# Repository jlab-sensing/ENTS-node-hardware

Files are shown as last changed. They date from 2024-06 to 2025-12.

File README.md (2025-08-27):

# Environmental NeTwork Sensor (ENTS) Node Hardware

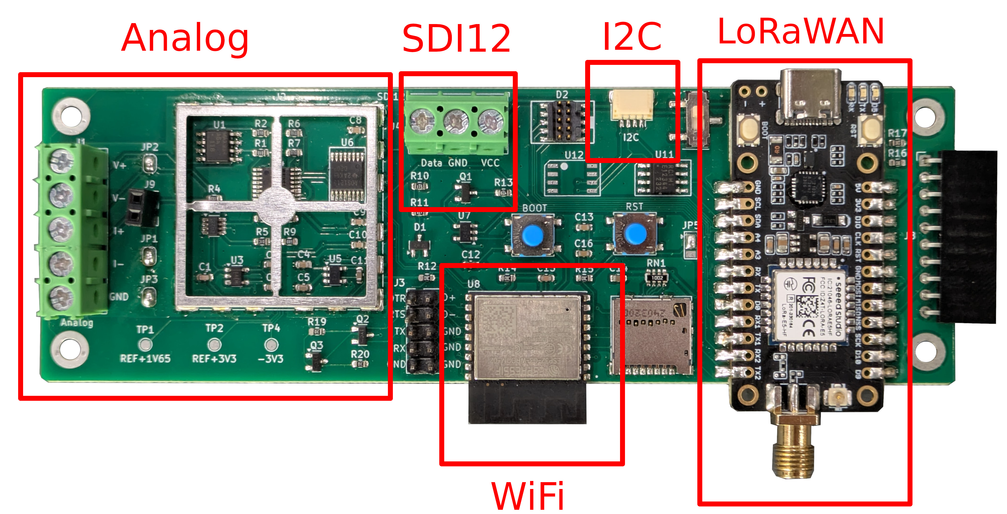
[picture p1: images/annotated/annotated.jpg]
Annotated Soil Power Sensor


This repo contains the EagleCAD source files for the PCB design of the Soil Power Sensor. The Soil Power Sensor is a iteration on the design of CurrentSense by Lab11(https://github.com/lab11/CurrentSense).

## BOM

The bill of materials is available digitally at https://octopart.com/bom-tool/nBygYAnz or as csv in `hardware/Soil Power Sensor.csv`.

There are two buttons not listed in the BOM for the esp32 `BOOT` and `EN`. These are cheaply available from amazon. Look for one with a 6mm by 6mm form factor.

Generate the BOM from the schematic editor (`Tools -> Generate Bill of Materials...`) and use the view *Order*.

## Assembly and QA Instructions

### Solder SMD components

We suggest ordering the boards SMD assembled through a PCB assembly service and have used [JLCPCB](https://jlcpcb.com/) in the past. Every component except the Wio-E5 module, 5-pin screw terminals, 3-pin screw terminals, and pin headers can be soldered by the assembly service. The component `U13` should not be populated by default and is used to expand the non-volatile memory of sensor measurements.

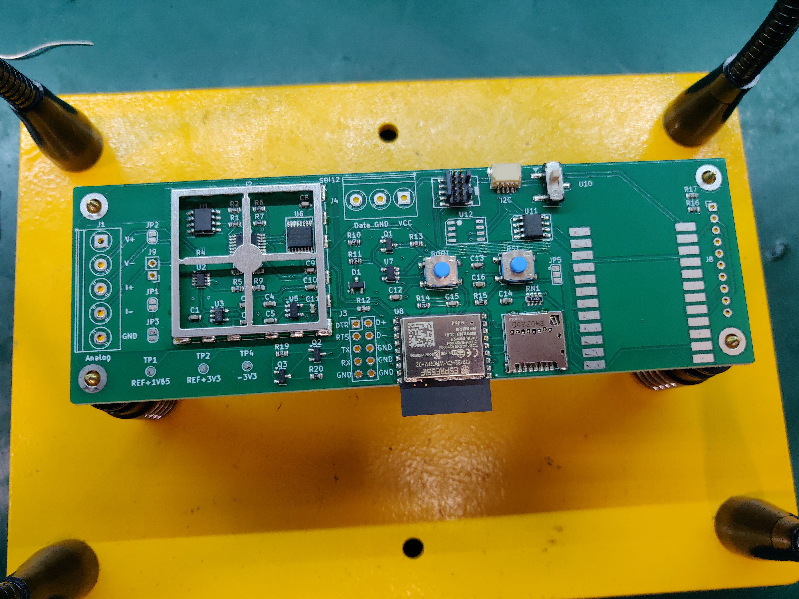
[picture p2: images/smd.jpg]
SMD Populated Board


### Solder Remaining Components

*Before soldering* visually inspect the boards for any solder bridges and defects. You do not want to solder the Wio-E5 module to a defective board as it accounts for half the cost of the board and cannot be desoldered easily.

1. Solder screw terminals at `J1`, `J4`, male pin-headers at `J3`, female right-angle pin headers at `J8`, and female pin headers at `J9`.
2. Solder the Wio-E5 module to the board. The USB-C connector should be facing the edge of the board closest to the switch, and RF terminal facing the microSD card module. The RF terminal should touching the edge of the board.
3. Use a multimeter to test for shorts between `GND` and `TP1`, `TP2`, `TP4`, `5V` on the Wio-E5, `3V3` on the Wio-E5, and `Vcc` on the 3-pin screw terminal. `TP4` maay display a resistance value due to capacitors.

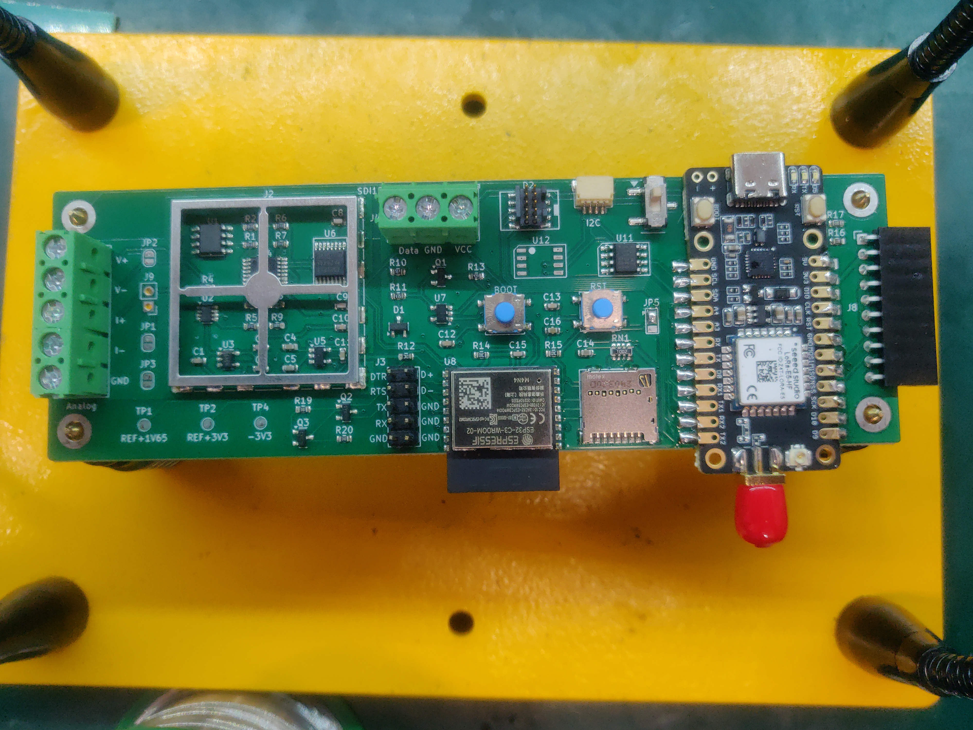
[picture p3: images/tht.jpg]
THT Populated Board


> NOTE: `J9` should be soldered with a female header to be used to connect a load. We did not have any 2x1 headers on hand so it is not shown in the picture.

### Check Power Rails

Then, power the device through the USB-C terminal with the power switch in the "UP" (close to nearest board edge). Verify the voltages at the test points match what is shown in the table. Some rails may be put in power down state by default and require firmware to be running to enable them.

`TP6` is used to used to connect the battery to the Wio-E5 module.

| Test point  | Signal | Voltage |
| ---  | --- | --- |
| `TP1` | `REF+1V65` | +1.65V  |
| `TP2` | `REF+3V3`  | +3.3V |
| `3V3` (Wio) | `+3V3` | +3.3V |
| `TP4` | `-3V3` | -3.3V |
| `TP5` | `VCC` | 5V |
| `5V` (Wio)  | `VUSB` | 5V |

### Load Firmware

See [ENTS-node-firmware](https://github.com/jlab-sensing/ENTS-node-firmware) for instructions on loading firmware on the device.

## Header definitions

### D2 (STM32 SWD)

Serial wire debug (SWD) port for stm32. To load the bootloader, hold `BOOT`, press and release `RST`, then release `BOOT`. Then you should be able to connect to the device.

### J9 (ESP32 Debug Header)

### J3 (ESP32 UART)

UART TX and RX pins to connect to the esp32 bootloader. Intended to be use with a USB to UART converter and `esptool.py`.

### J9 (Battery Connector)

Connect a battery module to the ENTS board. The header is reversible has the following pinout, where `~` represent inverse logic:

| `GND` |
| `3V3` |
| `~PG` |
| `~CHG` |
| `VBAT` |
| `VBAT` |
| `~CHG` |
| `~PG` |
| `3V3` |
| `GND` |

## Measurement configurations

The soil power sensor has multiple measurement configurations. The most common use case is *Common GND* which gives single ended measurements with low-side sensing.

### Independent Inputs (Default)

| Jumper | Bridged |
|---|---|
| `JP1` | No |
| `JP2` | No |
| `JP3` | No |

| Resistor | Value |
|---|---|
| `Rsense1` | DNP |

Inputs `Voltage`, `Current`, `GND` are all independent from each other, therefore the most modular configuration. Use this mode when you want to measure a voltage/current difference that is not relative to `GND`. The `GND` connection must be connected to the common ground of the measured device.

### Common `GND`

| Jumper | Bridged |
|---|---|
| `JP1` | Yes |
| `JP2` | No |
| `JP3` | Yes |

| Resistor | Value |
|---|---|
| `Rsense1` | 0 ohms |

The negative terminals of `Voltage` and `Current` are tied to ground. Both measurements will be relative to ground. Connect common ground to the negative terminals or `GND` terminal.

### Internal load

| Jumper | Bridged |
|---|---|
| `JP1` | Yes |
| `JP2` | Yes |
| `JP3` | Yes |

| Resistor | Value |
|---|---|
| `Rsense1` | Any |

The configuration uses a on-board resistor for `RSENSE1`. The resistor is chosen based on the desired range of input measurements. The board uses a high-side current measurements.

## Userful links

Links for generating production files and BOM for [JLCPCB](https://jlcpcb.com/)

- [Gerber and drill/map files](https://jlcpcb.com/help/article/how-to-generate-gerber-and-drill-files-in-kicad-8)
- [BOM and centroid files](https://jlcpcb.com/help/article/How-to-generate-the-BOM-and-Centroid-file-from-KiCAD)

## License & Copyright

The Soil Power Sensor board design files are licensed under the Solderpad Hardware License (wraparound license of Apache License).

## Maintainers

- John Madden - [jmadden173](https://github.com/jmadden173)

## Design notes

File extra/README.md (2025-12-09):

# Extras

Extra resources supporting development.

- `analog_multiplexer/`: PCB for multiplexing analog input channels
- `battery_connector/`: PCB for converting 2.54mm header to 5-pin JST connector
- `i2c_breakout/`: PCB to expose additional I2C connectors and regulate to a 3.3V source
- `mounting_plate/`: 3D-printed mounting plate for ENTS-nodes
- `newbatt`: PCB for powering the ENTS-node from a battery
- `sdi12_breakout`: PCB to expose additional SDI-12 terminals
- `usb_to_ttl/`: PCB for plug-in-play debugging of the esp32

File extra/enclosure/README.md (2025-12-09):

# Enclosure V2

> NOTE: This is an iteration on the enclosure designed by UC San Diego students available [here](https://github.com/jlab-sensing/ENTS-enclosure). Notably the board mounts to the screw portion of the enclosure rather than the static cap. This makes assembly/removal of the board easier. The original repo is a good reference for detailed assembly instructions and cost.

## Instructions

1. 3D print the *base*, *mount*, and *guide*.
1. Cut PVC tube to desired length (TBD length).
1. Use PVC primer and cement to attach both end caps.
1. Use the *guide* to drill holes in the screw off end cap.
1. Use a step drill to enlarge the holes to fit cable glands.
1. Press threaded inserts into the mount.
1. Superglue the mount to the base.
1. Superglue the base to the screw cap.
1. Install cable glands.

## Materials

| Item | Link |
|---|---|
| PVC Tube | [McMaster](https://www.mcmaster.com/2426k93/) |
| PVC End Cap | [McMaster](https://www.mcmaster.com/9102K224/) |
| PVC Threaded Adapter | [McMaster](https://www.mcmaster.com/9102K354/) |
| PVC Threaded End Cap | [McMaster](https://www.mcmaster.com/9102K334/) |
| PVC Primer | [McMaster](https://www.mcmaster.com/18815K51/) |
| PVC Cement | [McMaster](https://www.mcmaster.com/74605a911/) |
| 3D Printer | Prusa Preferred |
| M3 x 6mm x 5mm Inserts | [Amazon](https://www.amazon.com/dp/B0CTCSJ8YT?ref=fed_asin_title&th=1) |
| M3 Standoffs | [Amazon](https://www.amazon.com/dp/B07KWVD986?ref=fed_asin_title) |
| M3 x 6mm Screws | [Amazon](https://a.co/d/5NEkSzM) |
| Cable Gland (Teros) | TODO |
| Cable Gland (Power) | TODO |

## Pictures

TODO

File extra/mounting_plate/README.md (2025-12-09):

# Mounting Plate for ENTS-nodes

3D-printed mounting plate for ENTS-nodes. Useful for airgapping metal pins from conductive surfaces and mounting the nodes securely.

## Materials

| Item | Link |
|---|---|
| M3 x 6mm x 5mm Inserts | [Amazon](https://www.amazon.com/dp/B0CTCSJ8YT?ref=fed_asin_title&th=1) |
| M3 Standoffs | [Amazon](https://www.amazon.com/dp/B07KWVD986?ref=fed_asin_title) |
| M3 x 6mm Screws | [Amazon](https://a.co/d/5NEkSzM) |

## Photo

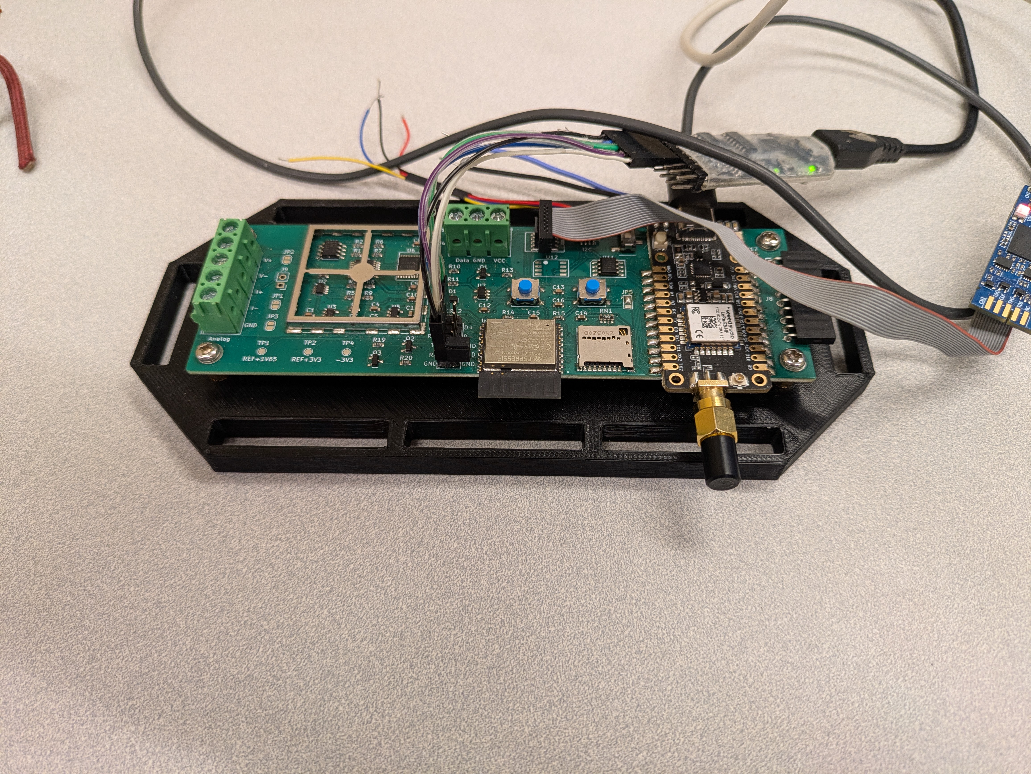
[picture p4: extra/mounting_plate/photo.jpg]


## Drawing

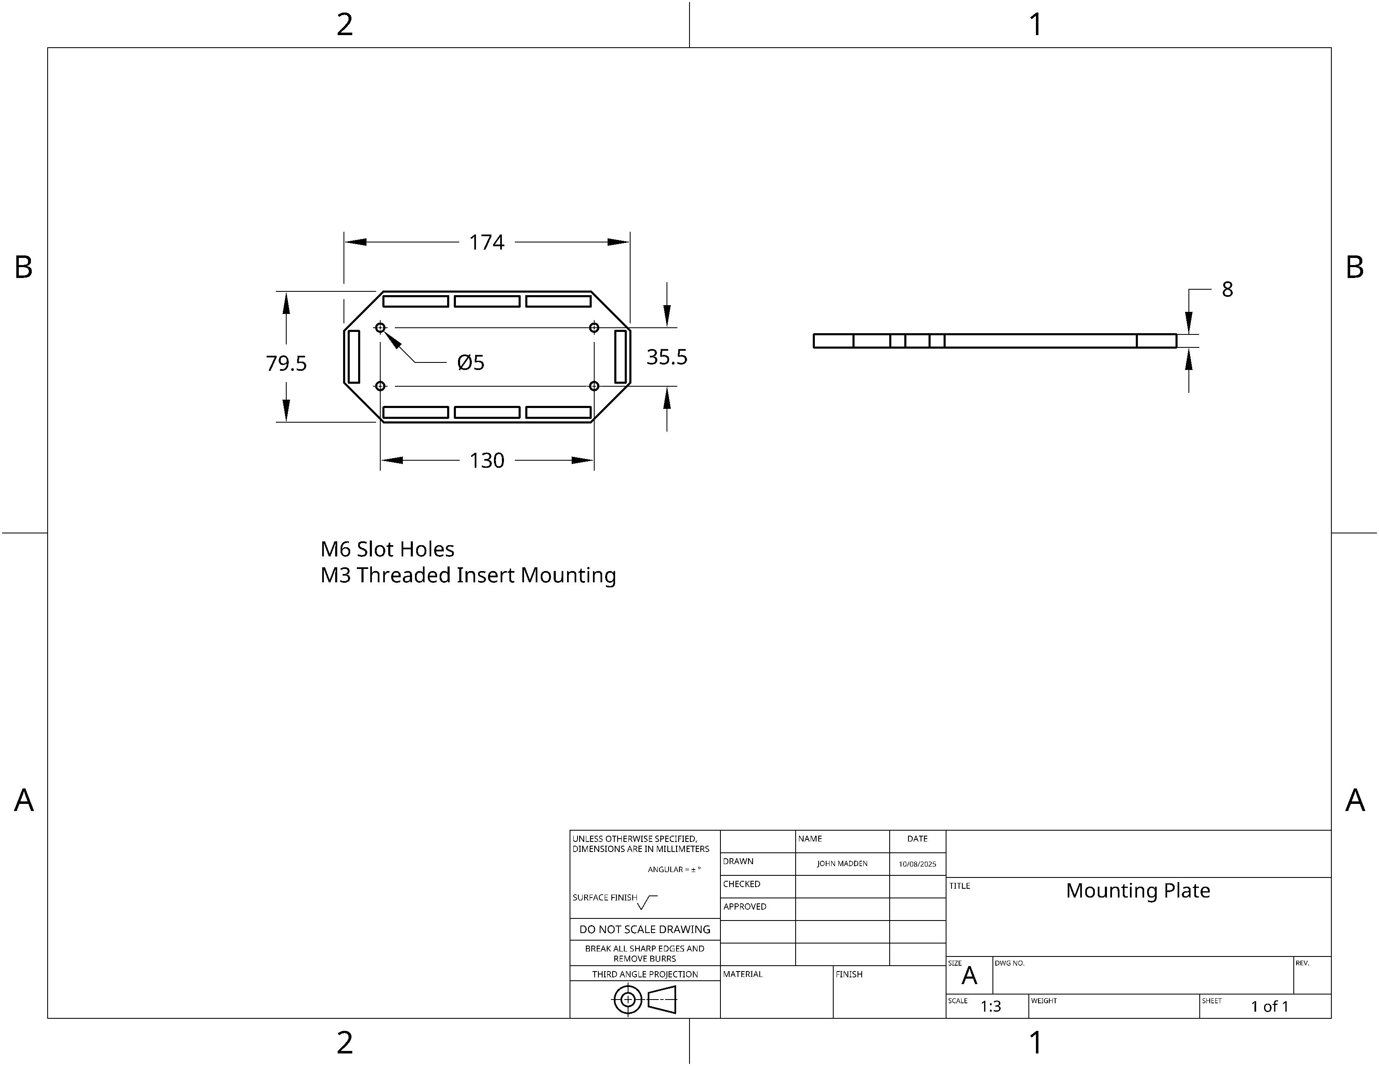
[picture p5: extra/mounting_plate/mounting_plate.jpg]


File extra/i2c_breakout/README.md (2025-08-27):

# SDI12 Breakout Board

This board add additional SDI-12 headers for connecting sensors. It also adds 3.5mm audio jacks that are commonly seen on SDI-12 sensors from METER.

| Top View | Bottom View |
| --- | --- |
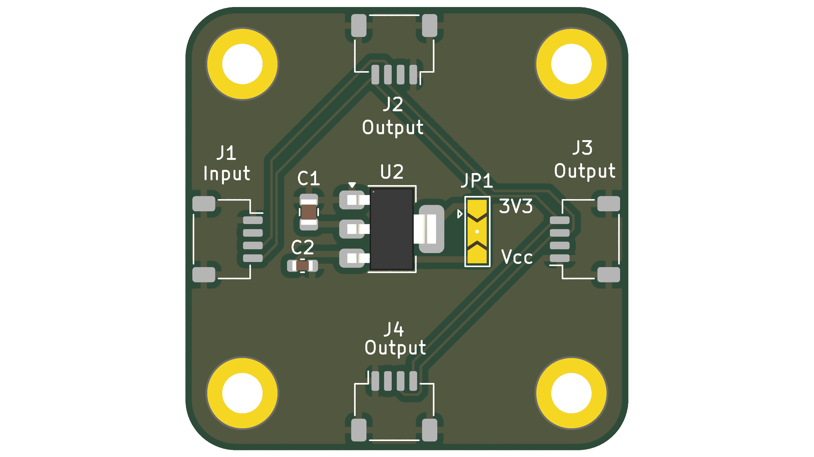
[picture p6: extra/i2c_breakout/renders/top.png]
Top View
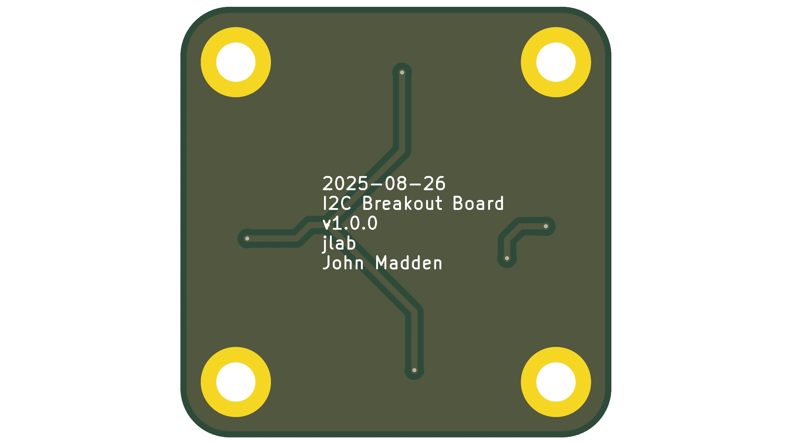
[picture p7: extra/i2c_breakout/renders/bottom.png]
Bottom View
|  |  |

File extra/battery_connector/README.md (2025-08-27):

# Battery Connector

The board adapts the old 10-pin molex connector to a better 5-pin JST connector.

| Top View | Bottom View |
| --- | --- |
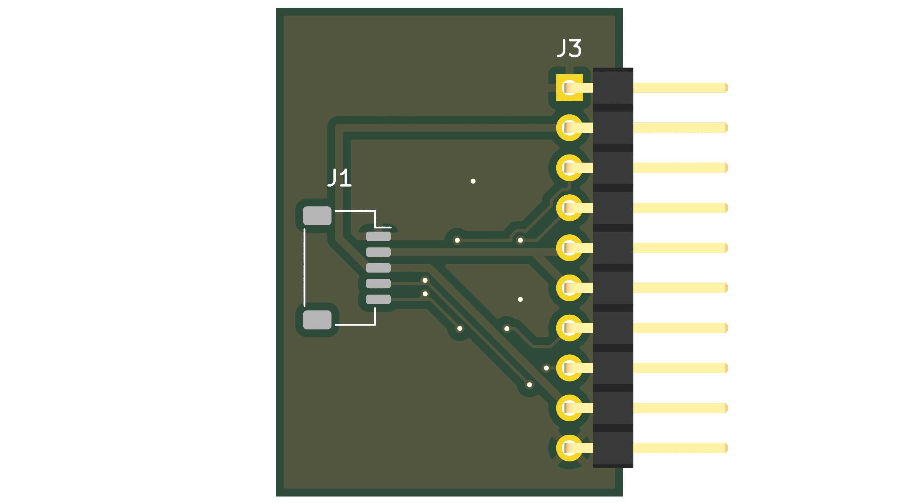
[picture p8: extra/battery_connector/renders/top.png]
Top View
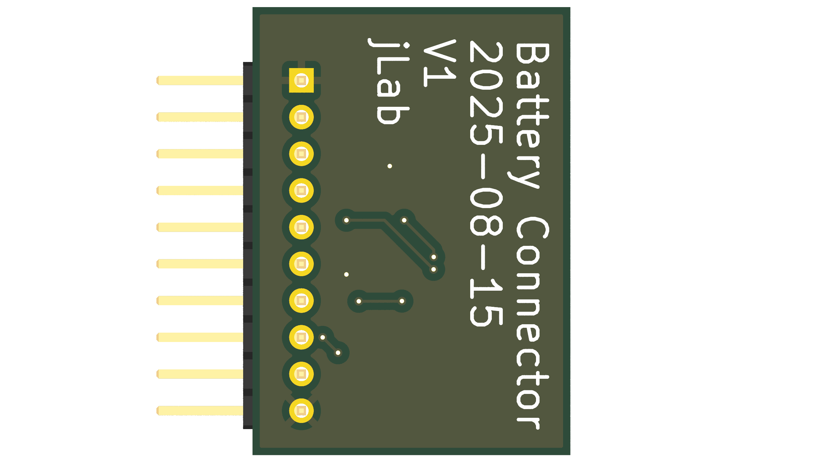
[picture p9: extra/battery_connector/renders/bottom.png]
Bottom View
|  |  |

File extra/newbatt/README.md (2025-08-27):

# Battery Board

The battery board adds two 18650 Li-ion battery and integrates a solar MPPT chip for charging. It uses a 5-pin JST connector to the ENTS board.

**Pin Configuration**

| # | Pin | Description |
|---| ---|---|
| 1 | GND | Ground |
| 2 | VBAT  | Battery voltage |
| 3 | 3.3V  | Regulated 3.3V |
| 4 | !PG | Power Good |
| 5 | !CHG  | Charging status |

| Top View |
| --- |
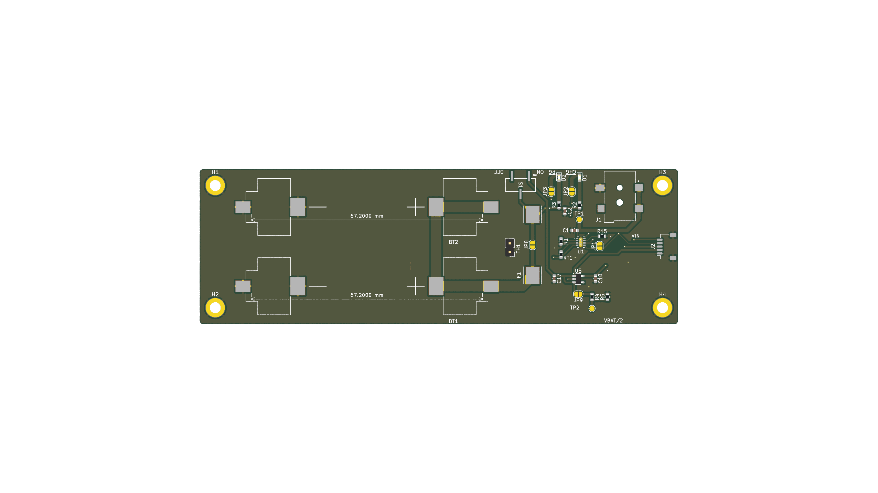
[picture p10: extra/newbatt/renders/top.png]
Top View
|  |

| Bottom View |
| --- |
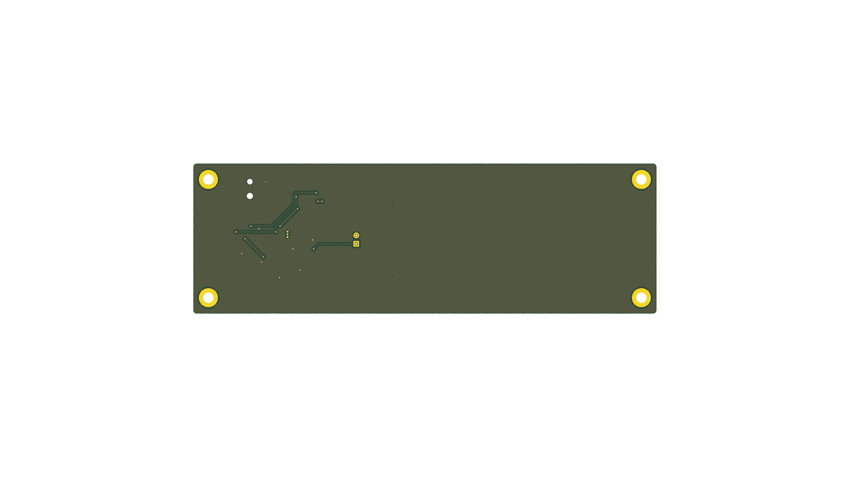
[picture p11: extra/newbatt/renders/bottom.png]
Bottom View
|  |

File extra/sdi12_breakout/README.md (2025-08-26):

# I2C Breakout Board

The breakout board is intended to add additional headers for external I2C devices. The header labeled input expects 5V input from the I2C header and steps the voltage down to `3V3` for compatibility with Adafruit devices. If this is not desired, the power jumper can be changed.

| Top View | Bottom View |
| --- | --- |
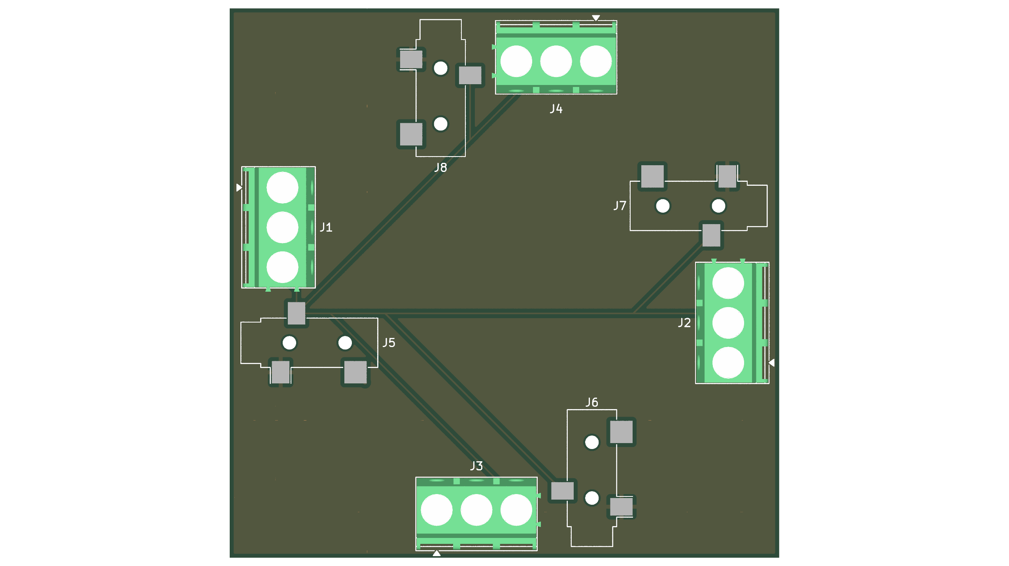
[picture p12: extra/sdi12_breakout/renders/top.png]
Top View
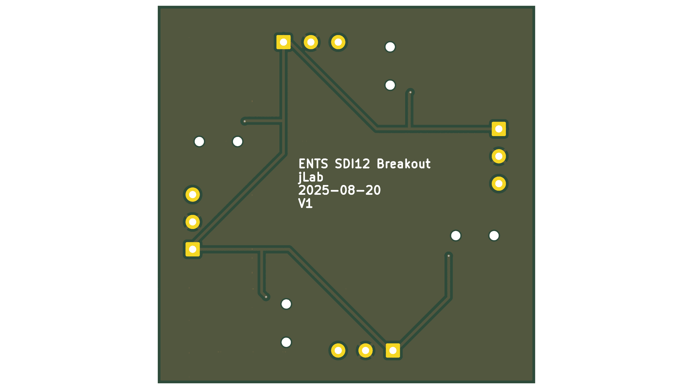
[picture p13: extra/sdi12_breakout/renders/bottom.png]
Bottom View
|  |  |

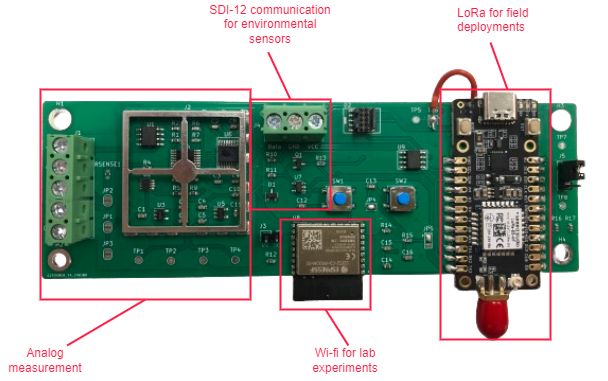
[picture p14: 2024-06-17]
images/sps.png

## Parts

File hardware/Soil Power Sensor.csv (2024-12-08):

Reference | Value | Footprint | Qty | MPN | LCSC
C1,C6,C7,C8,C9,C10,C12,C13,C15 | 0.1uF | Capacitor_SMD:C_0603_1608Metric | 9 | CC0603KPX7R7BB104
C4,C5,C11,C16 | 1uF | Capacitor_SMD:C_0603_1608Metric | 4 | CC0603KRX5R7BB105
C14 | 10uF | Capacitor_SMD:C_0603_1608Metric | 1 | CC0603KRX5R5BB106
D1 | BZX84Cxx | Package_TO_SOT_SMD:SOT-23 | 1 | BZX84C7V5LT1G | C12729
D2 | ARM10_DEBUG | Soil Power Sensor:ARM10_DEBUG | 1 | FTSH-105-01-LM-DV-K | C2874168
J1 | Screw_Terminal_01x05 | TerminalBlock_Phoenix:TerminalBlock_Phoenix_PT-1,5-5-5.0-H_1x05_P5.00mm_Horizontal | 1 | 1935190
J2 | RFShield_OnePiece | RF_Shielding:Wuerth_36103305_30x30mm | 1 | 36103305S | C7386557
J3 | Debug | Connector_PinHeader_2.54mm:PinHeader_2x05_P2.54mm_Vertical | 1
J4 | Conn_01x03 | TerminalBlock_Phoenix:TerminalBlock_Phoenix_PT-1,5-3-5.0-H_1x03_P5.00mm_Horizontal | 1 | 1935174
J5 | Micro_SD_Card | Connector_Card:microSD_HC_Molex_104031-0811 | 1 | 1040310811 | C585350
J6 | RFShield_OnePiece |  | 1 | 36003300S
J7 | Conn_01x04_Socket | Connector_JST:JST_SH_SM04B-SRSS-TB_1x04-1MP_P1.00mm_Horizontal | 1 | SM04B-SRSS-TB | C160404
J8 | Conn_01x10 | Connector_PinHeader_2.54mm:PinHeader_1x10_P2.54mm_Horizontal | 1
J9 | Rsense | Connector_PinHeader_2.54mm:PinHeader_1x02_P2.54mm_Vertical | 1
Q1 | BSS123 | Package_TO_SOT_SMD:SOT-23 | 1 | BSS123-7-F | C85107
Q2,Q3 | L8050QLT1G | Package_TO_SOT_SMD:SOT-23 | 2
R1,R2,R6,R7 | 100k | Resistor_SMD:R_0603_1608Metric | 4 | RT0603BRD07100KL | C122538
R3,R5 | 10k | Resistor_SMD:R_0603_1608Metric | 2 | RT0603BRD0710KL | C95204
R4 | 330m | Resistor_SMD:R_0603_1608Metric | 1 | PT0603FR-070R33L | C20160671
R8,R9 | 499k | Resistor_SMD:R_0603_1608Metric | 2 | RT0603BRD07499KL | C515607
R10,R11 | 510 | Resistor_SMD:R_0603_1608Metric | 2 | RC0603FR-07510RL | C114670
R12,R14,R15 | 10k | Resistor_SMD:R_0603_1608Metric | 3 | RC0603FR-0710KL | C98220
R13 | 47k | Resistor_SMD:R_0603_1608Metric | 1 | RC0603FR-0747KL | C105579
R16,R17 | 1M | Resistor_SMD:R_0603_1608Metric | 2
R19,R20 | 10k | Resistor_SMD:R_0603_1608Metric | 2
RN1 | 10k | Resistor_SMD:R_Array_Convex_4x0603 | 1 | YC164-JR-1310KL | C110924
SW1 | BOOT | Button_Switch_SMD:SW_Push_1P1T_NO_CK_KSC7xxJ | 1 | KSC741JLFS | C221766
SW2 | EN | Button_Switch_SMD:SW_Push_1P1T_NO_CK_KSC7xxJ | 1 | KSC741JLFS | C221766
SW3 | SW_SPDT | Soil Power Sensor:JS102011SCQN | 1 | JS102011SCQN | C221661
U1 | MAX9944 | Soil Power Sensor:SOIC127P600X155-8N | 1 | MAX9944ASA+T
U2 | INA296A | Package_TO_SOT_SMD:SOT-23-8 | 1 | INA296A5IDDFR | C7577680
U3 | REF2033 | Package_TO_SOT_SMD:SOT-23-5 | 1 | REF2033QDDCRQ1
U4 | THS4532 | Soil Power Sensor:SOP65P640X120-16N | 1 | THS4532IPW | C2059559
U5 | TPS60400DBV | Package_TO_SOT_SMD:SOT-23-5 | 1 | TPS60400DBVR
U6 | ADS1219 | Soil Power Sensor:TSSOP65P640X120-16 | 1 | ADS1219IPWR
U7 | SN74LVC1G240 | Package_TO_SOT_SMD:SOT-23-5 | 1 | SN74LVC1G240DBVR
U8 | ESP32-C3-WROOM-02-N4 | Soil Power Sensor:MODULE_ESP32-C3-WROOM-02-N4 | 1 | ESP32-C3-WROOM-02-H4
U10 | Wio-E5 mini | Soil Power Sensor:WIO-E5_MINI | 1 | 113990939
U11 | MB85RC1MT | Soil Power Sensor:SOP127P505X155-8N | 1 | FM24CL16B-G

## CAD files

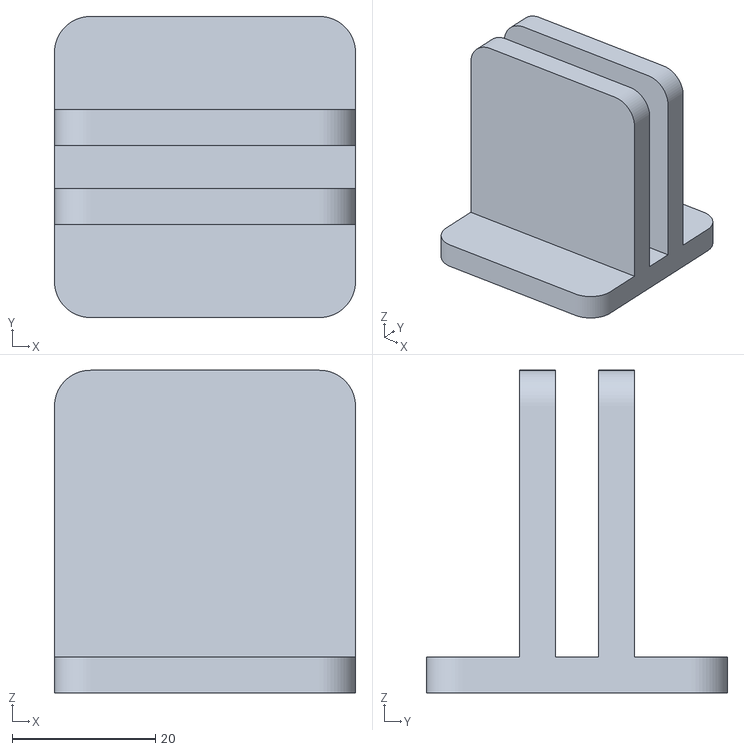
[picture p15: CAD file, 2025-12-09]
extra/enclosure/base.stl
42.0 x 42.0 x 45.0

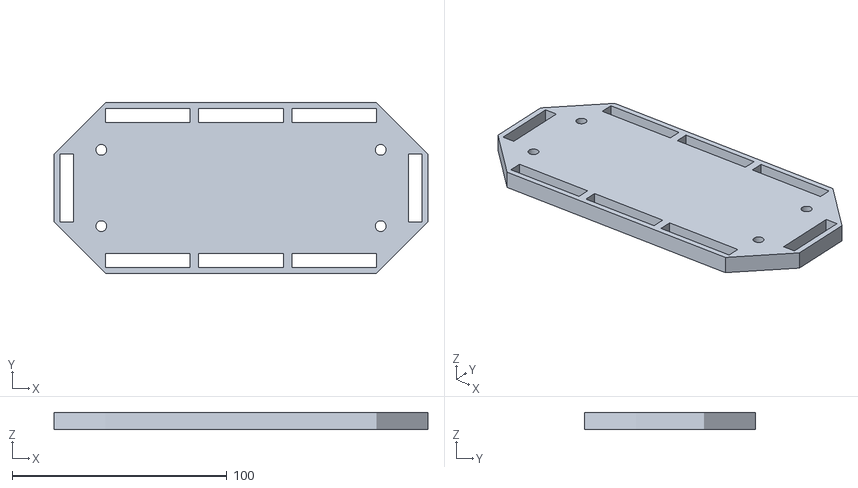
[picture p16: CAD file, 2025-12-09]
extra/mounting_plate/mounting_plate.stl
174.0 x 79.5 x 8.00

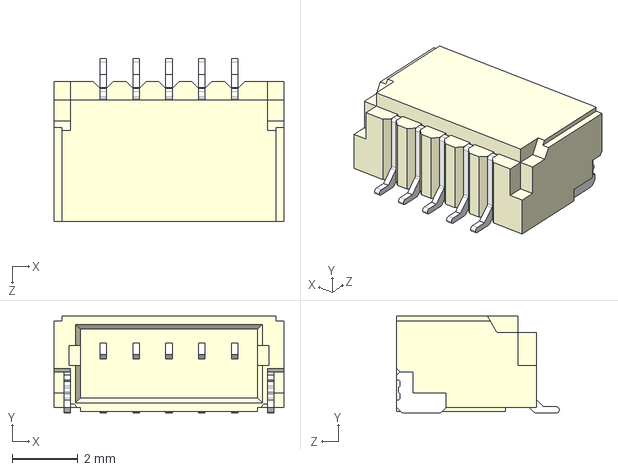
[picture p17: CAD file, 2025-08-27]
extra/newbatt/3dmodels/SM05B-SRSS-TB.STEP
7.00 x 2.95 x 4.95 mm

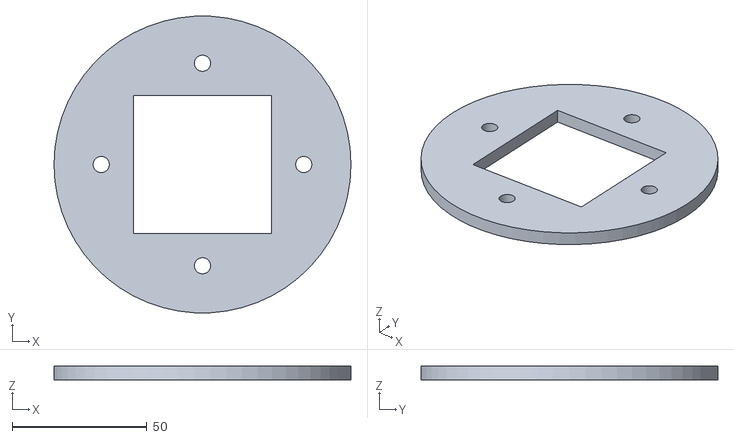
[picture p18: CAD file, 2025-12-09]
extra/enclosure/guide.stl
110.0 x 109.8 x 5.00

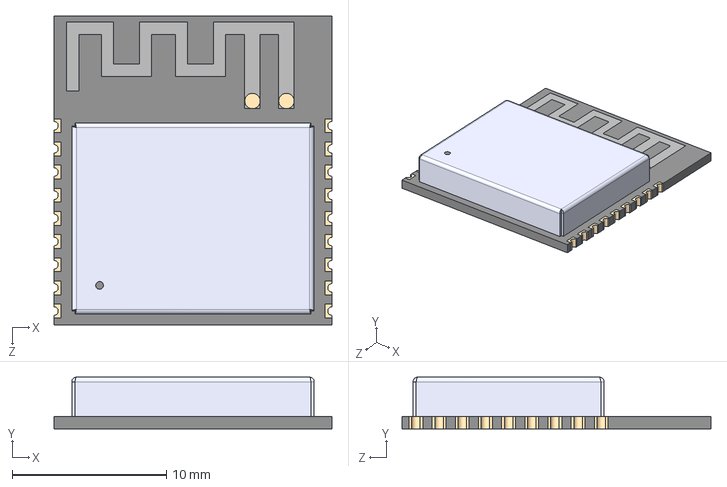
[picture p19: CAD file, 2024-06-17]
hardware/3dmodels/ESP32-C3-WROOM-02-H4.step
18.0 x 3.35 x 20.0 mm

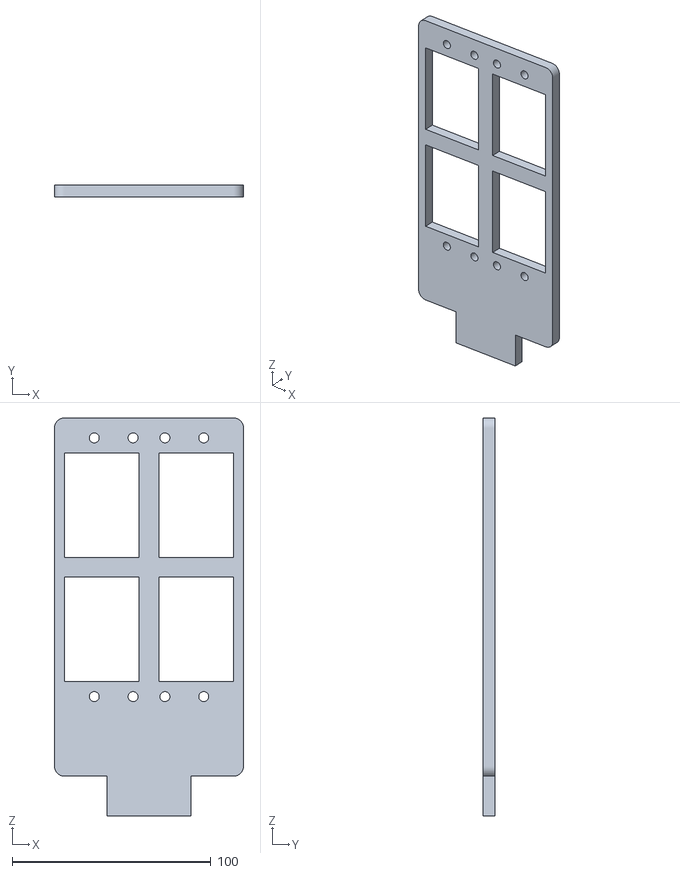
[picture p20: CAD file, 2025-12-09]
extra/enclosure/mount.stl
95.0 x 6.00 x 200.0

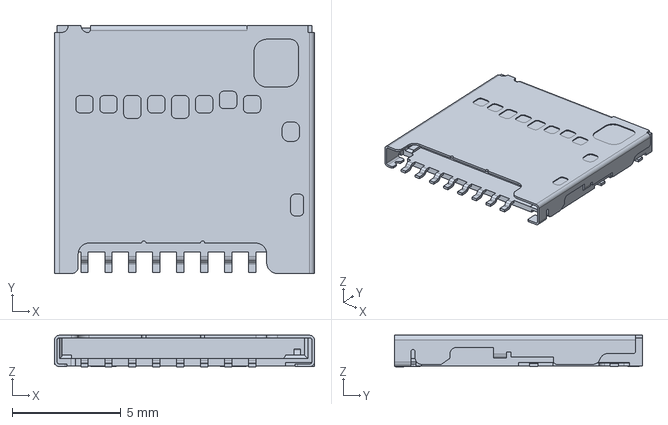
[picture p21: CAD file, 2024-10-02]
hardware/3dmodels/1040310811.stp
11.9 x 11.4 x 1.45 mm

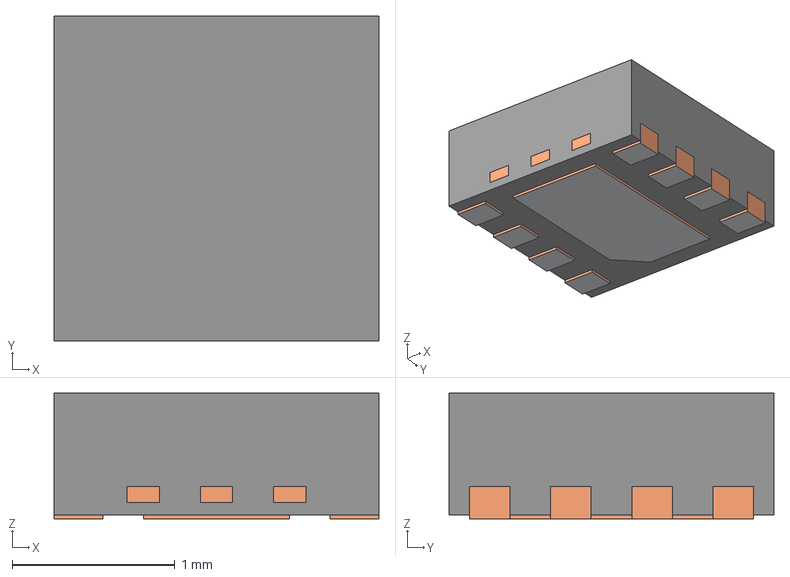
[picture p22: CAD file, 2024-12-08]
extra/newbatt/3dmodels/BQ25172_DSG0008A.stp
2.00 x 2.00 x 0.775 mm
BODY-SON
FRAME-DSG0008A
PIN1-ID

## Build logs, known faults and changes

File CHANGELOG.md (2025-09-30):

# Changelog

All notable changes to this project will be documented in this file.

The format is based on [Keep a Changelog](https://keepachangelog.com/en/1.0.0/), and this project adheres to [Semantic Versioning](https://semver.org/spec/v2.0.0.html).

## [Unreleased] - TBD

## Added

- I2C multiplexer board ([#67](i67),[#68](i68))
- SDI12 multiplexer board ([#70](i70))
- USB-to-TTL debug probe ([#73](i73])
- Analog multiplexer ([#72](i72))

## Updated

- Battery connector to JST ([i71](i71))

[i67]: https://github.com/jlab-sensing/ENTS-node-hardware/issues/67
[i68]: https://github.com/jlab-sensing/ENTS-node-hardware/issues/68
[i70]: https://github.com/jlab-sensing/ENTS-node-hardware/issues/70
[i71]: https://github.com/jlab-sensing/ENTS-node-hardware/issues/71
[i72]: https://github.com/jlab-sensing/ENTS-node-hardware/issues/72
[i73]: https://github.com/jlab-sensing/ENTS-node-hardware/issues/73

## [2.2.3] - 2024-12-04

### Added

- Added pinout for D+/D- for debugging ([#59](i59))
- Added RTS and DTR for automatic bootloader ([#58](i58))
- Add battery breakout board ([#55](i55))

### Updated

- Replaced Rsense with header for THT resistor ([#60](i60))
- Updated switch configuration for battery board ([#57](i57))

[i55]: https://github.com/jlab-sensing/ENTS-node-hardware/issues/55
[i57]: https://github.com/jlab-sensing/ENTS-node-hardware/issues/57
[i58]: https://github.com/jlab-sensing/ENTS-node-hardware/issues/58
[i59]: https://github.com/jlab-sensing/ENTS-node-hardware/issues/58
[i60]: https://github.com/jlab-sensing/ENTS-node-hardware/issues/60

## [2.2.2] - 2024-08-14

### Updated

- Fixed footprint for RN1 ([#45](i45))
- Footprint of power switch to include orientation ([#45](i45))

### Removed

- Filtering capacitors C2, C3 ([#44](i44))

[i44]: https://github.com/jlab-sensing/soil_power_sensor/issues/44
[i45]: https://github.com/jlab-sensing/soil_power_sensor/issues/45
[i46]: https://github.com/jlab-sensing/soil_power_sensor/issues/46

## [2.2.1] - 2024-07-26

### Added

- Power switch in place of jumpers ([#35](i35))
- 4 pin 1mm JST SH connector for external i2c sensors based on the Adafruit STEMMA QT standard ([#29](i29))
- microSD card slot ([#41](i41))
- Second FRAM IC position

### Updated

- ESP32 UART terminal to a 4-pin header ([#38](i38))
- Battery connector to 4xAAA with case from Keystone ([#36](i36))
- FRAM footprint for compatibility with alternative IC (MB85RC1MT)
- Doubled trace with for power (0.4mm)

[i29]: https://github.com/jlab-sensing/soil_power_sensor/issues/29
[i35]: https://github.com/jlab-sensing/soil_power_sensor/issues/35
[i36]: https://github.com/jlab-sensing/soil_power_sensor/issues/36
[i38]: https://github.com/jlab-sensing/soil_power_sensor/issues/38
[i41]: https://github.com/jlab-sensing/soil_power_sensor/issues/41

## [2.2.0] - 2024-03-08

> Updated to KiCAD 8.0 in this release.

### Added

- RF shield over analog components
- Screw mounting holes with GND connection
- Hardware UART to SDI12 converter
- Added test point for hand soldering Vcc to positive terminal on Wio-E5
- Buttons for EN and BOOT pins for ESP32

### Updated

- ESP32-C3-MINI-N1 to ESP32-C3-WROOM-02-N4
- Updated screw terminal to 5 channel from Phoenix
- Updated SDI12 terminal to 3 channel from Phoenix

### Removed

- Through hole mount for Rsense

## [2.1.0] - 2023-11-09

Migrated from Autodesk Eagle to KiCAD

### Added

- Test points for supply rails (#7)
- Connection from INA296 Vcc to STM32 GPIO (#12)
- Header for USB Serial/JTAG controller on ESP32
- Added header for Rsense
- Added xfer equations on schematic and PCB
- Library devices
    - WIO-E5_MINI
    - ADS1219
    - FM24CL16B
    - ARM10_DEBUG

### Changed

- Replaced Wio-E5 with daughter board equivalent, the Wio-E5 mini (#2)
- Debug headers to the ARM10 connector (#3)
- Updated ADC from MAX11208 to ADS1219 (#10)
- Replaced LM27761 with TSP60400 (#4)
- Resistor values for voltage/current channels (#5)
- Communication between ESP32 and STM32 to I2C
- ESP32_EN signal to a pull-up configuration
- Replaced Rsense header with 0603 pad
- Connected REF203 EN pin to POWERDOWN signal
- Update low pass filter cutoff frequency
- Library device
    - AAA55
    - MAX9944
    - THS4532
    - INA296

### Depreciated

N/A

### Removed

- Board wide ground planes (#11)
- Physical reset switch for ESP32

### Security

N/A

## [2.0.0-a.6] - 2023-05-10

### Schematic

- Updated current gain resistors

## [2.0.0-a.5] - 2023-05-02

### Schematic

- Removed buffer on negative rail and replaced MAX9944 with 
- Added values to parts missing VALUE text
- Renumbered all parts
- Remove power test points
- Added MPN to all passive components

### Board

- Iterate on board design
- Added UC Santa Cruz Logo
- Removed tValues
- Generated gerber files
- Updated low pass filter capacitance values
- Replaced 100nF capacitors with 0.1uF
- Replaced 250k resistors to 249K based on availability
- Replaced 0804 footprints with 0603

### Library

- Added MAX9943 device
- Added prefix for -3V3
- Updated LM27751 footprint
- Updated MAX9943 footprints

### Other

- Added source files for logos

## [2.0.0-a.4] - 2023-04-26

### Schematic

- Fixed duplicated naming for NRST net between STM32 and ESP32
- Fixed name of FSA2466 symbol
- Renamed differential pair nets to allow for differential pair routing
- Replaced Vcc on STM32 JTAG with +3V3

- Added experiment drawings

### Library

- Updated MAX9944 footprint
- Updated AAA55 Footprint

### Board

- Created initial layout for board

## [2.0.0-a.3] - 2023-04-11

### Schematic

- Removed jumper for 4th AAA battery cell
- Added document title and revision to frames
- Added TVS diode for both USB signal channels
- Fixed in-situ load connections
- Replaced FDA LTC6362 with THS4532IPW
- Moved multiplexer to analog signal side to reduce the number of ADCs as a cost saving measure
- Replaced low current main LDO TPS7A2033 with 1A TLV1117LV

- Replaced REF1933 with REF2033 due to availability
- Replaced TPS60403 with LM27761 due to availability

- Connected ESP32 EN pin to STM32 PA9 pin
- Connected STM32 PC0 to THS4532 PD pin
- Connected STM32 PC1 to EN on REF2033 and LM27761

### Library

- Verified footprints of all devices and fixed where applicable
- Added devices to Soil Power Sensor Library
	- TPD2E2U06DCKR
	- THS4532IPW
	- REF2033
	- LM27761
- Removed devices from Soil Power Sensor Library
	- MAX9918
	- LTC6362
	- STM32 Devices
	- Random oscillators
- Moved Wio-E5 to Soil Power Sensor library
- Defined attributes in CONTRIBUTING.md for efficient BOM generation

## [2.0.0-a.2] - 2023-03-14

### Added

- Added in-situ Rload
- Added connection for TEROS-12
- Added JTAG connection for STM32
- Added voltage monitoring circuit
- Added test points
- Added LP filter on signals leading to ADC
- Added FSA2466UMX to library
- Added Wifi Module (ESP32-C3)
- Added ESP32-C3-MINI-1-N4 to library
- Added TLV1117LV33DCYR to library
- Added battery with selectables jumpers
- Added AAA55
- Added Wio E5 and USB
- Added device MI0805K601R-10
- Added device MODULE_LORA_E5
- Added LT234XD-R device

### Fixed

- Fixed voltage and current connectors
- Fixed ADC interface with mux

### Changed

- Updated JTAG connector for ESP32
- Updated TLV1117LV33DCYR in library
- Moved power to seperate sheet

### Removed

None

## [2.0.0-a.1] - 2023-02-02

Initial design for Soil Power Sensor v2

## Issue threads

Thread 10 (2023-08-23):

Update ADC

jmadden173, 2023-08-23:
Replace ADC with 2 channels to remove the mux and support I2C to unify communication protocols

- [x] Find ADC
- [x] Create library device
- [x] Update schematic
- [ ] Update board

jmadden173, 2023-08-31:
This ADC is acceptable; [ADS1219IPWR](https://www.digikey.com/en/products/detail/texas-instruments/ADS1219IPWR/9597825)

Closed 2023-09-11.

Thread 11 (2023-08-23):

Fix ground planes

jmadden173, 2023-08-23:
It was impossible to solder. Limit ground planes to analog sensing and fix through hole component connections.

Closed 2023-08-25.

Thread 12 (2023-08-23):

Add switch for power hungry components

jmadden173, 2023-08-23:
The CSA consumes 2.5mA and has no way of going into a sleep state. Would offer significant power savings in sleep state.

- [ ] Find switching component (Analog swtich, bjt, etc.)
- [ ] Add device to library
- [x] Update schematic
- [ ] Update board

jmadden173, 2023-09-11:
It looks like an analog component isn't necessary. Instead, analog components can be powered directly from the GPIO pins. Below is the max electrical ratings for the GPIO. It is well above the 2.5mA of the most power-hungry component.

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

jmadden173, 2023-09-11:
Left MAX9944 connected to +3V3 and -3V3 continuously since there was no similar way of turning off the -3V3 rail. It also only draws 550uA.

Closed 2023-09-11.

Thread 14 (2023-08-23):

Fix voltage input buffer

jmadden173, 2023-08-23:
Voltage input requires buffers on both (+) and (-) inputs. They are both being measured from ground than between them. The current configuration allows current to flow from (-) to GND.

Closed 2023-08-25.

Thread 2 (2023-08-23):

Replace Wio-E5 module with daughter board equivalent

jmadden173, 2023-08-23:
Replace with Wio-E5 mini (https://wiki.seeedstudio.com/LoRa_E5_mini/)

- [x] Create library device
- [x] Update schematic
- [x] Update board

Closed 2023-08-24.

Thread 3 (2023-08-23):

Fix debug headers

jmadden173, 2023-08-23:
- [x] Find proper headers for SWID and ST-Link
- [x] Update schematic
- [x] Updated board

jmadden173, 2023-08-25:
In the [STLINK-V3PWR UM](https://www.st.com/resource/en/user_manual/um3097-source-measurement-unit-smu-and-debuggerprogrammer-for-stm32-microcontrollers-stmicroelectronics.pdf), Table 19 shows the connection for the `ARM10/MIPI10-compatible connector`.

jmadden173, 2023-08-25:
The Blackmagic MCU debugger [pinout](https://black-magic.org/knowledge/pinouts.html#arm-cortex-debug-connectors) also uses the `ARM Cortex 10pin Debug Connector`

jmadden173, 2023-08-25:
Wire: https://www.digikey.com/en/products/detail/samtec-inc/FFSD-05-D-05-00-01-N/6678070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

Connector: https://www.digikey.com/en/products/detail/cnc-tech/3220-10-0300-00/3883266

Closed 2023-08-25.

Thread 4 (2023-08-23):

Replace QFN with leaded packages

jmadden173, 2023-08-23:
- [x] Find all QFN packages
- [x] Create library devices
- [x] Update schematic
- [ ] Update board

jmadden173, 2023-08-31:
QFN Packages
- ESP32 -- Keeping because there is no better options
- FSA2466 -- Getting removed as ADC is being replaced
- LM27761 -- Replace with TPS60400. There's already an upstream regulator for the 3.3V rail so it should be a drop in replacement. It has a much better package; SOT-23.

Complete #10 before this

Closed 2023-09-11.

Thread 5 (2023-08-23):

Fix resistor values

jmadden173, 2023-08-23:
Some of the resistor values were initially calculated wrong with the correct ones listed in my senior thesis.

- Change current circuit differential amp to all 100k resistors for unity gain
- Change Rsense to 16.5 ohms

Closed 2023-09-11.

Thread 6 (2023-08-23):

Add fuses

jmadden173, 2023-08-23:
Fuses would be nice for 5V, 3.3V and battery

- [ ] Calculate estimate of power consumption
- [ ] Create library device
- [ ] Update schematic
- [ ] Updated board

jmadden173, 2023-09-11:
I'm not sure how necessary these are. My concern is added complexity and parasitic resistance driving up power consumption.

Closed 2023-09-11.

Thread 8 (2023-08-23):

Remove vias under battery clips

jmadden173, 2023-08-23:
Could possibly cause a short when clips are soldered directly above

Closed 2023-09-12.

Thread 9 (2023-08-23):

Add NVM

jmadden173, 2023-08-23:
Add the [FM24CL16B-G](https://www.digikey.com/en/products/detail/infineon-technologies/FM24CL16B-G/3788653) IC

- [x] Add device to library
- [x] Update schematic
- [ ] Update board

Closed 2023-09-11.

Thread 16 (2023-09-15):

Migrate from Eagle 9.6.2 to KiCAD 7.0.7

jmadden173, 2023-09-15:
- [x] Import EAGLE project to KiCAD using built-in importer
- [x] Replace components with KiCAD equivalents (eg. resistors)
- [x] Update imported components not found in KiCAD libraries
- [x] Update footprints for symbols
- [x] Re-place components on board mimicking layout in Eagle
- [x] Check/Fix ERC
- [x] Check/Fix DRC

jmadden173, 2023-09-15:
This youtube looks good: https://www.youtube.com/watch?v=7C3CkiXf65Q

jmadden173, 2023-09-15:
Good tutorial for creating symbols: https://forum.kicad.info/t/tutorial-how-to-make-a-symbol-kicad-v5-1-x/13336/3
Tutorial on BOM: https://forum.kicad.info/t/how-to-create-a-bill-of-materials-bom/12346

jmadden173, 2023-09-15:
The workflow for migrating components appears to be the following:
1. Import EAGLE project to KiCAD using built-in importer
2. Replace components with KiCAD equivalents (eg. resistors)
3. Update imported components not found in KiCAD libraries
4. Update footprints for symbols
5. Re-place components on board mimicking layout in Eagle

jmadden173, 2023-10-03:
Image showing traces from Eagle

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

Closed 2023-10-12.

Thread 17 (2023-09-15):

Revert changes on voltage channel

jmadden173, 2023-09-15:
The initial change to unity gain diff amp was to have all the same unity gain resistor values. It turns out that 16.5 ohm sense resistor doesn't really exist since it so high of a value. I already have the parts so I was going to revert the changes.

Closed 2023-10-12.

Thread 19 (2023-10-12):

Implement feedback changes for 2.1.0

jmadden173, 2023-10-12:
- [x] Add header for Rload resistor in series with SMD
- [x] Add silkscreened box to board for extra writing
- [x] Add equations for solving for channel saturation on schematic and board
- [x] Export PDFs to Github repo

Closed 2023-10-15.

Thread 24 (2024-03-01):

Add hardware for SDI-12

jmadden173, 2024-03-01:
See https://permalink.lanl.gov/object/tr?what=info:lanl-repo/lareport/LA-UR-15-26961. Looks like it involves a level shifter and another IC for switching between RX and TX.

Related issue: https://github.com/jlab-sensing/soil-power-sensor-firmware/issues/47

jmadden173, 2024-03-07:
Going with the circuit referenced here since it level shifts both ways: https://www.daycounter.com/Circuits/SDI-12/SDI-12-Interface.phtml

Closed 2024-06-17.

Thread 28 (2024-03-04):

Fix Vcc header

jmadden173, 2024-03-04:
The Vcc header is not configured properly so that voltage from Vbat will provide power to the Wio-E5 module.

jmadden173, 2024-03-08:
Handled by soldering a wire from Vcc on our board to the + terminal on the Wio-E5

Closed 2024-06-17.

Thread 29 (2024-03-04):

Add header for external sensors

jmadden173, 2024-03-04:
Unsure exactly what this would look like, but eventually we will need a way to add new novel sensors to the device. It could be something as simple as adding pins for the I2C lines. Open to ideas.

jmadden173, 2024-06-26:
Through my experience with the bme280 sensors, we can add a 1mm JST connector (commonly known as Quiic Connect from Sparkfun or STEMMA QT from Adafuit. There's also a standard 2mm JST connect that's used by some Adafruit products as STEMMA and Seeedstudio as Grove. We can easily crimp a 1mm to 2mm JST or have it breakout into jumper wires. Thinking about adding multiple terminals to make it easier to add multiple devices.

jmadden173, 2024-07-22:
Found part number for JST connector: https://www.digikey.com/en/products/detail/jst-sales-america-inc/SM04B-SRSS-TB/926710

Closed 2024-07-23.

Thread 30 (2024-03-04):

3D printable waterproof case

jmadden173, 2024-03-04:
Currently we are using waterproof enclosures that cost as much as the device. A waterproof enclosure should be possible that reduces the size and footprint of the device.

jmadden173, 2024-09-25:
References to panel mount connects that we can use on the enclosure:
USB-C Panel Mount: https://www.digikey.com/en/products/detail/weipu-connector/SY2512-SUSB3-0-C/24639186
5-pin Panel Mount: https://www.digikey.com/en/products/detail/te-connectivity-amp-connectors/T4111002051-000/6679519

jmadden173, 2024-09-26:
Better suggestion here: https://www.data-alliance.net/cable-gland-for-fiber-usb-sim-terminal-block-waterproof-ip67-feed-thru/

The cable gland allows for it to attached and detached away from the buried enclosure. Therefore the board enclosure would not need to be dug up to interface with the board.

jmadden173, 2025-08-08:
Done, created a separate repo for implementation: https://github.com/jlab-sensing/ENTS-enclosure

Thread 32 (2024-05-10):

Fix BOM

jmadden173, 2024-05-10:
Remove MPN for buttons as they are cheaply available on amazon. Same footprint is valid.
Update the `10k` resistor to the correct MPN

Closed 2024-06-17.

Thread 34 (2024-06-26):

Replace debug header with board to board connector

jmadden173, 2024-06-26:
This part is recommended for the ST-Link V3 MINIE which has board to board connectors. Would reduce the cost of the board and push the cost to the development hardware.

https://www.digikey.com/en/products/detail/kyocera-avx/009159010061911/11307835

jmadden173, 2024-07-22:
Something to look at in the future, but currently the connector is working just fine. Therefore removing from milestone

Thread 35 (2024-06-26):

Add power switch

jmadden173, 2024-06-26:
Power switch would allow the device to be turned off and therefore not logging and using battery when being transferred to field deployments.

jmadden173, 2024-07-23:
Use the following DP3T switch for both 3.3V and VCC: https://www.digikey.com/en/products/detail/c-k/JS203011JCQN/6137632

Closed 2024-08-14.

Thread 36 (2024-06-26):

Replace battery connector with AA compatable.

jmadden173, 2024-06-26:
Found out during a deployment that the current battery solution is prone to shorting and blowing the traces between batteries. The easiest fix is plastic battery connectors. Switching to AA batteries will more than double the battery capacity (1900 mAh) vs AAA 750 mAh capacity.

jmadden173, 2024-07-24:
This also includes increasing the trace width for power connections

Closed 2024-08-14.

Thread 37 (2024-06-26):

Add LEDs for esp32 UART

jmadden173, 2024-06-26:
TX and RX LEDs will be very helpful when debugging.

jmadden173, 2024-07-22:
Adding TX and RX LEDs directly causes a lot of current draw on the lines resulting in signal degradation. Alternative would be adding an opamp to the lines which adds more components. See https://electronics.stackexchange.com/questions/124618/how-do-i-hook-up-an-led-across-the-tx-pin-on-my-atmega328

Instead I recommend using USB to TTL converters with status LEDs built in as most modules come with baked in support. Example [here](https://www.amazon.com/HiLetgo-CP2102-Converter-Adapter-Downloader/dp/B00LODGRV8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)

Closed 2024-07-22.

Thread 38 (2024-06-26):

Add GND pin on esp32 UART connection

jmadden173, 2024-06-26:
GND pin would more easily allow for USB to UART connectors to be plugged in. Would eliminate the need for running external wires.

Closed 2024-06-26.

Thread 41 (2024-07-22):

Add SD card slot

jmadden173, 2024-07-22:

jmadden173, 2024-07-25:
[This](https://www.programming-electronics-diy.xyz/2022/07/sd-card-tutorial-interfacing-sd-card.html) website has a comprehensive guide for setting up an SD card with a microcontroller.

Looks like pull-up resistors are required for some of the components according to SD card specifications. A resistors array like the [YC164-JR-1310KL](https://www.digikey.com/en/products/detail/yageo/YC164-JR-1310KL/17023153) should work.

Closed 2024-08-14.

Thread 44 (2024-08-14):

Remove filter capacitors

jmadden173, 2024-08-14:
C2 and C3 appear to cause unwanted noise in the measurement circuit. When removed from a prototype board, the issue appears to be fixed and the curves are linear.

Closed 2024-08-29.

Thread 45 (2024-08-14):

Fix resistor array sizing

jmadden173, 2024-08-14:
Resistor array for the micro SD card is the wrong size. Turns out that KiCAD specifies resistors in the derived type while Digikey specifies it in total package size. Experimentally figure out the followng:
- Roughly a 1206 Digikey is a 0603 KiCAD
- Roughly a 2012 Digikey is a 1206 KiCAD

Need to replace the footprint for RN1 with 4x0603.

Until then can use the following replacement 2012 array: [YC324-JK-0710KL](https://www.digikey.com/en/products/detail/yageo/YC324-JK-0710KL/1005309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)

Closed 2024-08-29.

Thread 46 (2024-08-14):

Place marker for switch orientation

jmadden173, 2024-08-14:
The power switch orientation matters on the board due to the position of the common pin. The C&K symbol should be at the top of the board.

Closed 2024-08-28.

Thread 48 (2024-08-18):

Add external wakeup line for esp32

jmadden173, 2024-08-18:
The esp32 has limited wakeup capabilities from sleep states. It was originally assumed that the i2c could wake up the device whenever a request came in from the stm32. This is not the case and an external trigger is the most applicable way of waking it from a sleep state. Therefore a line needs to be connected from one of the stm32 gpio pins to the esp32 ext0, ext1 lines.

jmadden173, 2024-09-04:
Esp32 Arduino reference for sleep modes: https://docs.espressif.com/projects/arduino-esp32/en/latest/api/deepsleep.html#about

>   /*
    First we configure the wake up source
    We set our ESP32 to wake up for an external trigger.
    There are two types for ESP32, ext0 and ext1 .
    ext0 uses RTC_IO to wakeup thus requires RTC peripherals
    to be on while ext1 uses RTC Controller so does not need
    peripherals to be powered on.
    Note that using internal pullups/pulldowns also requires
    RTC peripherals to be turned on.
  */

So we should use the ext1 pin to for the wakeup line.

jmadden173, 2024-09-04:
The ext1 pin is multiplexed to the RTC pins with names from the base `ESP32-C3` module. RTC pins are not listed in the datasheet but mapped to the module pins. `GPIO3` aka `IO3` in KiCAD would work.

DS: https://www.espressif.com/sites/default/files/documentation/esp32-c3-wroom-02_datasheet_en.pdf
Module pinout: https://docs.espressif.com/projects/esp-idf/en/latest/esp32c3/api-reference/peripherals/gpio.html

Closed 2024-09-04.

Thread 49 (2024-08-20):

Update name references to ENTS

jmadden173, 2024-08-20:
Name of the project changed from soil power sensor to Environmental Network Sensor (ENTS). The repo name and README has already been updated but the name within the KiCAD files also needs to be updated to avoid confusion.

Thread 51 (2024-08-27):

Cosmetic: Move silk for terminal block connections

ppannuto, 2024-08-27:
Currently, when wires are screwed into the terminal block `J1`, the wires cover the silkscreen labeling which makes it hard to double-check config at a glance.

Closed 2024-09-04.

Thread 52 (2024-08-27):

Cosmetic: Draw a large rectangle of silkscreen on the board for IDs

ppannuto, 2024-08-27:
You can avoid labels / stickers if you leave a region on the PCB to write on; a large block of silkscreen makes things readable.

e.g. from a board I have, this is the BLE MAC address (and also board id), where only the last two octets change, so most of the MAC is written out, with two boxes to write on for the last octets.

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

It looks a little funny b/c my easy to grab screenshot has both the top and bottom silk showing, since we write IDs on both sides of the boards.

Closed 2024-09-04.

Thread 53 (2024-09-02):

Nonlinearity near channel bounds

jmadden173, 2024-09-02:
Noticed nonlinearity at the bounds of both the voltage and current channels. A stopgap solution is to limit the voltage range to -2V to 2V and the current channel to -0.9mA to 0.9mA.

Current hypothesis is the 3.3V LDO or -3.3 charge pump are dropping too much voltage resulting in the nonlinear behavior.

jmadden173, 2024-12-08:
Possibly related to #64

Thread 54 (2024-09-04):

Fix microSD card slot

jmadden173, 2024-09-04:
When placing the prefab component order, I realized that the SD card slot is backwards and needs to be fixed. Additionally replace the component with one available on jlcpcb parts.

Closed 2024-09-04.

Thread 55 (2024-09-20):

Support for battery charging

jmadden173, 2024-09-20:
While brainstorming the waterproof enclosure for the board, we realized that if the device is buried underground and the batteries run out of charge, the enclosure would need to be dug up and batteries replaced. Battery charging via an external connection fix this issue.

Brainstorming is required to determine the type of battery (stick with AA, or other form factor) and how we are going to integrate the charging circuit. I think there will be some difficulty

jmadden173, 2024-10-02:
Proof there is NiMH battery charging ICs that can be integrated on the board.
https://www.digikey.com/en/products/detail/texas-instruments/BQ25172DSGR/16585660

jmadden173, 2024-10-08:
Wikipedia has a good reference for comparison between battery technologies available [here](https://en.wikipedia.org/wiki/Comparison_of_commercial_battery_types#cite_note-OEM-33). The Enloop AA batteries are considered *low self discharge* making it comparable to LiPo and Li-ion. There's also [this](https://openenergymonitor.blogspot.com/2013/10/aa-battery-considerations.html) website that tracked the discharge rate of multiple battery types.

Unless there are any objections, I think we should stick to NiMH as already planned as we won't risk issues with moving to a 3.7V battery that can cause unforeseen side effects.

I listed the chip above to see if a multi-cell charger exists. Usually we prefer using ICs with non-QFN style pads (pads underneath the package) so that we can inspect the solder connections, so I would look around for other chips. Bonus points if they are available and in-stock on [JLCPCB parts](https://jlcpcb.com/parts).

jlin143, 2024-10-08:
Need some requirements on:
1. Size (volume)
2. Capacity and/or minimum lifetime (with charge, without charge)
3. Voltage (min, max, ideal/nominal)
4. Current discharge rate (min, max, average)
5. Weight
6. Operational temperature

jlin143, 2024-10-09:
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

3D render of a draft of the NiMH battery module based on the BQ25172 NiMH BMS. This model does not include solar MPPT or separate power path (i.e. battery and Vout are shorted). Will upload the design files to hardware shortly. To do:

- Fix DRC errors
	- Silkscreen overlaps
	- JLCPCB constraints (min clearance, etc)
	- Ground plane fill minimum spokes on USB-C connector through-holes.
- Select a 4-slot AAA tray instead of 2x 2-slot AAA trays.
- Reduce the number of input connectors to <= 2.
	- Currently have 2.1mm barrel, screw terminal, USB-C, micro USB.
- Consider moving from through-hole resistors and capacitors to SMD.
	- This does mean that the ease of modification is reduced.
- Move battery trays to underside. Requires less through-hole components to be used.
- Standoff and mounting holes, to be coordinated with the node mainboard and enclosure limitations.
- Consider board-to-board pin header connection (ex. arduino shield-esque) instead of screw terminal output.
- Source an equivalent thermistor (Semitech 103AT-2) on digikey. The recommended thermistor is not in stock on digikey.

jmadden173, 2024-11-12:
Reference to pinout
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

jlin143, 2024-11-13:
Updated schematic and PCB with part selection info and adjusted the battery cell footprint in commit 15fccb8429cf77c0dc20af99edd72b60c186cc3b. Should be ready for order / pull request. I recommend a small batch to verify the battery clip placement and spacing. The datasheet did not provide much information on the bend and stiffness of the battery tab, and despite the common name of 18650, cells can vary between 65mm and 70mm.

For the battery selection, I recommend one of the following (in order from cheap to expensive at 50qty):
1. [66.92mm] https://www.18650batterystore.com/products/samsung-35e-button-top?variant=37145681690775
2. [65.25mm] https://www.18650batterystore.com/collections/18650-batteries/products/samsung-35e
3. [65.05mm] https://www.18650batterystore.com/collections/18650-batteries/products/molicel-m35a-18650-battery

jmadden173, 2024-12-06:
Notes from design review of ents before large order (2024-12-05)
- Tested supplying 3V3 to the output of the on-board LDO on the Wio-e5. Experimentally validated that the 60 ohm discharge resistor is not in effect when the output pin is powered from a external 3V3 rail.
- Plan is to add a physical switch on the ents board that switches between USB and Battery. Only the `Vcc` rail switch is needed since the regulated 3V3 rails (Wio-e5, battery, circuit 3V3) will all be connected together. The Wio-E5 3V3 rails acts as both a power input and output.
- Updated the battery board pinout in the following order
    1. GND
    2. VBAT
    3. 3V3
    4. PG
    5. CHG
    6. CHG
    7. PG
    8. 3V3
    9. VBAT
    10. GND

Changed needed on *battery*:
- [ ] Add LDO to battery board
- [ ] Update pinout
- [ ] Update switch to one available on JLCPCB

Changes needed for *mainboard*

- [ ] Update pinout
- [ ] Added switch for power
- [ ] Implement the login shown in the following image:

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

Closed 2024-12-08.

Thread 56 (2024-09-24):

Redesign battery design

jmadden173, 2024-09-24:
While brainstorming the waterproof enclosure for the board, we realized that if the device is buried underground and the batteries run out of charge, the enclosure would need to be dug up and batteries replaced. Battery charging via an external connection fix this issue. Need to rethink what battery to use and possibly a charging circuit so that the enclosure doesn't need to be opened.

jmadden173, 2024-09-25:
Proof there is NiMH battery charging ICs that can be integrated on the board.
https://www.digikey.com/en/products/detail/texas-instruments/BQ25172DSGR/16585660

jmadden173, 2024-10-02:
Closing as duplicate of #55

Closed 2024-10-02.

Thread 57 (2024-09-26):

Fix switch orientation

jmadden173, 2024-09-26:
The PCBA boards from JLCPCB came with the power switch backwards due to a miscommunication about orientation. They base it off the *C&K* symbol on the switch while I referenced the position in the datasheet. The correct orientation is with the *C&K* symbol at the "top" of the board closer to the USB-C connector. The silkscreen dot should be flipped vertically.

Closed 2024-12-08.

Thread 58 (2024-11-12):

Add RTS and DTR pinout on UART header

jmadden173, 2024-11-12:
RTS and CTS pins would allow `esptool.py` to properly reset the board after programming. This is important for remote testing on the esp32

jmadden173, 2024-11-12:
See the following for information on how to connect pins to module
https://dl.espressif.com/dl/schematics/SCH_ESP32-C3-DEVKITM-1_V1_20200915A.pdf

jmadden173, 2024-11-15:
More information on how to connect automatic reset lines. Also found out that its RTS and DTR for the automatic bootloader.

https://docs.espressif.com/projects/esptool/en/latest/esp32/advanced-topics/boot-mode-selection.html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

Closed 2024-12-08.

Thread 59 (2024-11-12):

Expose D+/D- pins for debugging

jmadden173, 2024-11-12:
Exposing pins and using a custom cable would allow for debugging support on the board.

https://docs.espressif.com/projects/esp-idf/en/v5.2.3/esp32c3/api-guides/jtag-debugging/index.html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

jmadden173, 2024-11-15:
Looking at the reference drawings on a board, I don't think resistors are necessary on the data lines.

Closed 2024-12-08.

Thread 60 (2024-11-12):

Add 2.2k resistor for `R_sense`

jmadden173, 2024-11-12:
This is the default for SMFC work so might as include it by default on the board and can be desoldered and replaced if needed.

jmadden173, 2024-12-08:
Switched to a 2-pin female header for support for 1/2 W resistors or other breakout boards.

Closed 2024-12-08.

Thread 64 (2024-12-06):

Replace MAX9944 with rail-to-rail input OpAmp

jmadden173, 2024-12-06:
The current op-amp buffers on the voltage measuring circuit are the [MAX9944](https://www.analog.com/media/en/technical-documentation/data-sheets/MAX9943-MAX9944.pdf) which I had originally thought were rail-to-rail input op-amps. In actuality the input voltage is limited to `Vcc - 1.8` according to the datasheet. We have observed a range of up to `2V` while connected to a `3V3` rail. To get the full range of our power supply we would need to replace the op-amp with a rail-to-rail input that has similar input characteristics to the *MAX9944*.

Another solution is powering the op-amp with the Vcc rail (either 5V for USB or 3.7V nominal for li-ion battery) since the voltage drop under battery is changing at a low frequency and typically PSRR are very high. The headroom on the op-amp will have to be enough to handle the battery drop down to approximately (3.4V). Possibly have to test at what voltage the power supply stopped outp[utting.

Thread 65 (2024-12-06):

Add range selection to channel

jmadden173, 2024-12-06:
For voltage channel a *HIGH* impedence voltage divider circuit will need to be added to select the range of the output. I believe a rotary knob will be the easiest for a user to select the range.

Similarly for the current channel, the sensor resistor can be adjusted to adjust the range of the current channel.

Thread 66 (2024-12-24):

External I2C device driving lines with 5V

jmadden173, 2024-12-24:
With using the [Adafruit BME280](https://www.adafruit.com/product/2652), the devices drives the pull-up resistors with the input from `V+`, and uses the input for the logic levels of the device. This means that when the BME280 is connected, there are external pull-ups connected to `5V`. When measured with the multimeter, the line voltage is `~3.8V`. So far the BME280 has been working with other devices, but should check the tolerances of other devices to prevent damage.

A stop gap solution would be to connect a 3V3 to a dupont, and connect that to `Vin` on the breakout board.

The connection was designed with the assumption that external devices would step the voltage down to 3V3.

Closed 2025-08-26.

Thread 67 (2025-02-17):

I2C voltage step down board

jmadden173, 2025-02-17:
5V is powering VCC on the I2C header causing adafruit based sensors to have 5V logic levels on the SDA, SCL lines. With pull-up resistors on the Wio-E5, the voltage levels of the I2C lines are ~3.7V which for now works because of 5V tolerant pins but am concerned if we start stacking more devices.

Proposing a breakout board that steps down the voltage and have multiple headers for connecting many sensors.

Closed 2025-08-26.

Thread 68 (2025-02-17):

I2C multiplexer breakout board

jmadden173, 2025-02-17:
In some use cases it would be good to have multiple of the same sensor to be connected to the same device. I'm proposing a breakout board that is able to multiplex I2C communication between the same devices.

Possibly combined with level shifting hardware in #67

Closed 2025-08-26.

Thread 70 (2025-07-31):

SDI-12 breakout board

jmadden173, 2025-07-31:
Currently we only have a single header for SDI-12 sensors. Multiple sensors would need to screw into the same interface which is non-optimal. We can have a breakout board with multiple headers that can be used to multiplex the SDI-12 on the ENTS board.

jmadden173, 2025-08-08:
Also would be helpful to put audio jack connectors for non-pigtailed sensors.

jmadden173, 2025-08-08:
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

Closed 2025-08-27.

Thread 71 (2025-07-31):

Improved battery board header

jmadden173, 2025-07-31:
The current 10-pin header takes up a lot of space and the wires get in the way of the enclosure. We can make a breakout board that uses the same header configuration that implements a JST or similar header as a better interface. The battery board will need to be modified with the updated header.

Currently we have significantly more ENTS boards than battery boards so we make an adapter for the ENTS boards.

Thanks Bill for the idea!

jmadden173, 2025-08-08:
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

Closed 2025-08-27.

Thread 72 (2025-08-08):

Analog multiplexer

jmadden173, 2025-08-08:
Create a board that multiplexes the analog frontend to allow for many different voltage measurements to be montitored. If I2C analog multiplexers exist that should be used. Otherwise we will likely need to into a GPIO line on the stm32.

Ideally it could be a board that is soldered to the screw terminal headers. Another alternative is making an analog frontend that connects to the I2C header of the board.

jmadden173, 2025-08-20:
You can use LDO `TLV117-3V3`

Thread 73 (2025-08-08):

USB to TTL adpater and debugger probe

jmadden173, 2025-08-08:
The esp32 uses a UART based bootloader for flashing the device. Another altnerative is *USB_CDC* using the exposed `D+/D-` pins. We have a header that external interfaces can be plugged in. We can create a interface using the `CP2102N` that allows for direct plug-in to the header on the ents board. Two USB interfaces (Type-C preferred) will be needed for both *USB to TTL* and *USB CDC*. There should be optional headers to expose all the pins on the `CP2102N`, aka (`DTR`, `DTS`, `RTS` `RTR`, etc).

TODO
- [x] Copy lines directly for `D+/D-` to connector. Layout the header.
- [x] Copy schematic for `CP2102` to kicad project
- [x] Reach out to @jmadden173 with layout
- [x] Connect remaining wires and verify
- [x] Layout board on PCB

jmadden173, 2025-08-15:
Should use `CP2102N-Axx-xQFN24` as it has separate VDD and VIO pins.

jmadden173, 2025-08-15:
Schematic to copy the CP2102N chip from. Source: https://dl.espressif.com/dl/schematics/SCH_ESP32-C3-DEVKITM-1_V1_20200915A.pdf

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

jmadden173, 2025-08-15:
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

jmadden173, 2025-08-15:
ESP32 Header: Source in the pdf of the `hardware/` folder in this repo.

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

Closed 2025-09-30.

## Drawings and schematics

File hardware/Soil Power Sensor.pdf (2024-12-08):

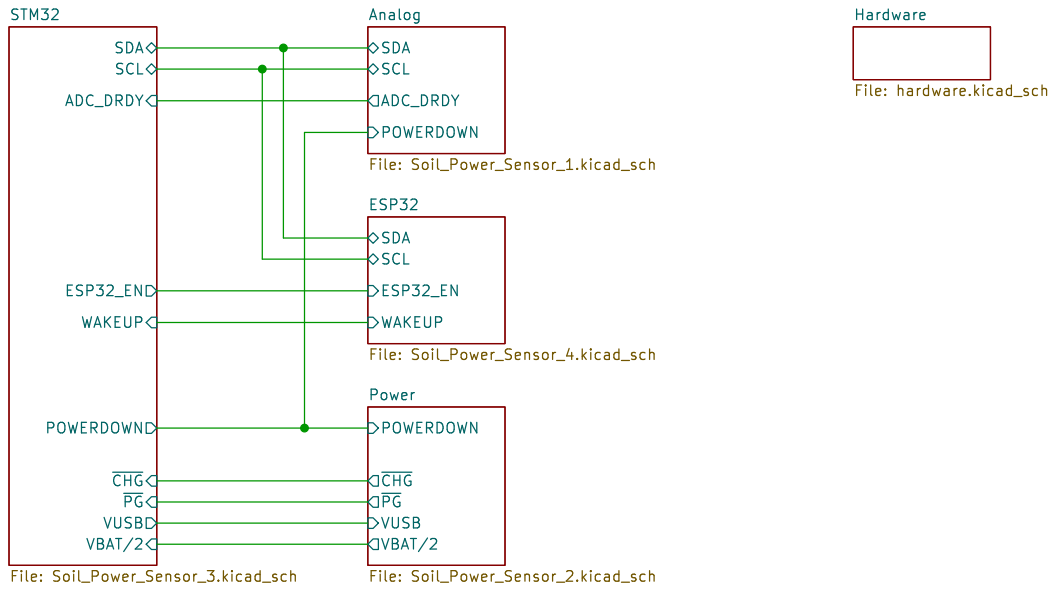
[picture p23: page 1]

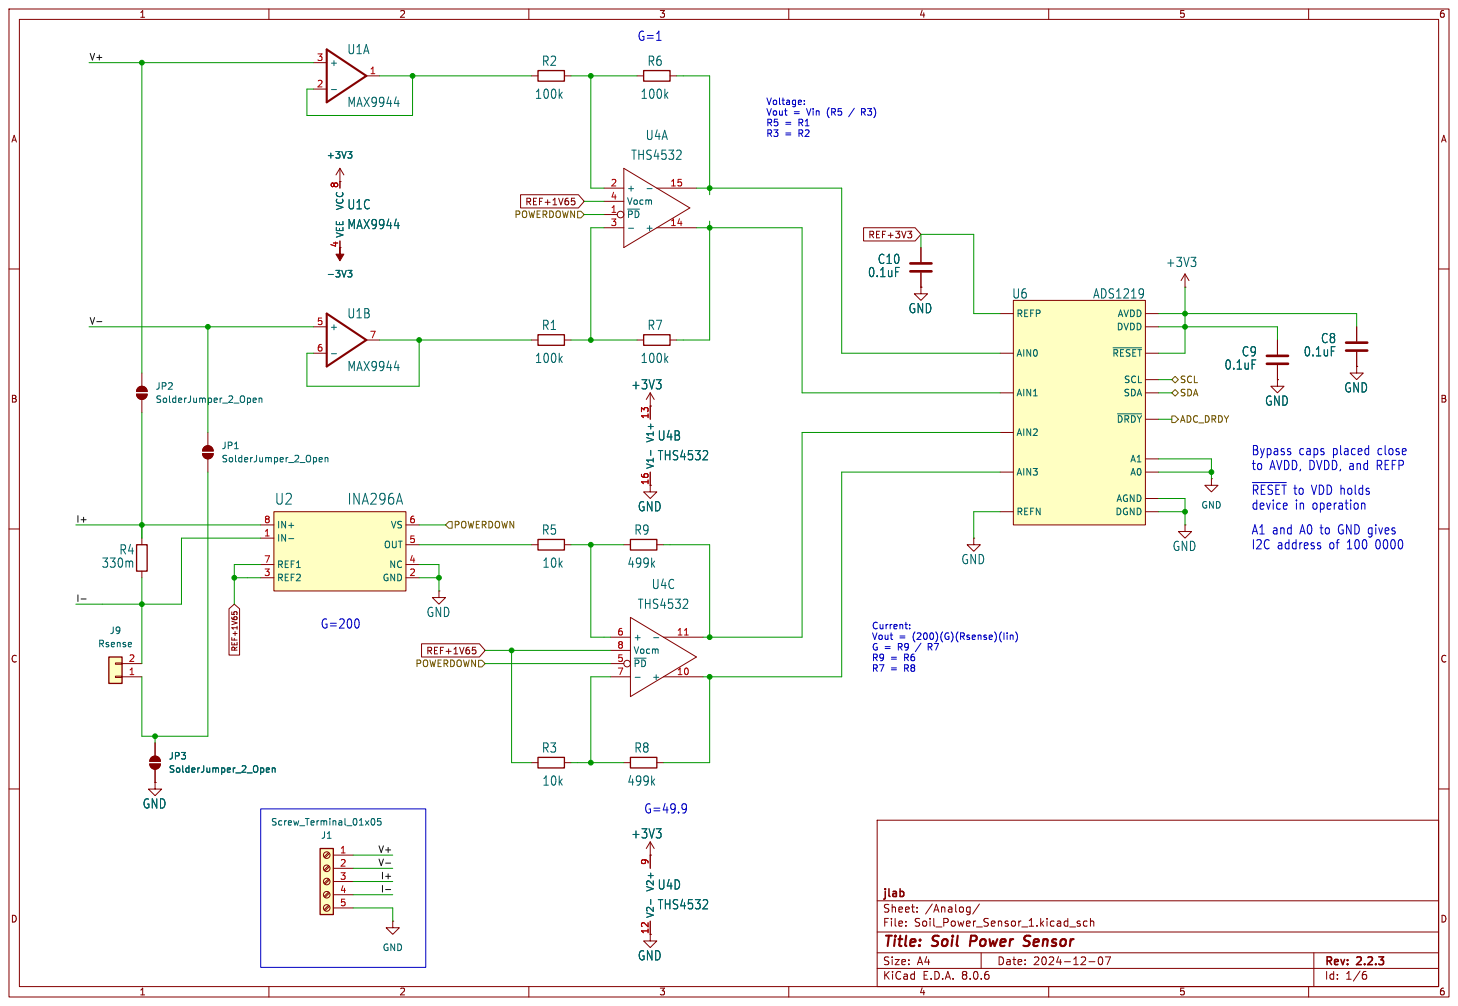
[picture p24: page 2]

SCL REF+3V3 REF+1V65 REF+1V65 REF+1V65

to AVDD, DVDD, and REFP
~{RESET}to VDD holds
device in operation
A1 and A0 to GND gives
I2C address of 100 0000

jlab
Id: 1/6 Title: Soil Power Sensor File: Soil_Power_Sensor_1.kicad_sch Sheet: /Analog/

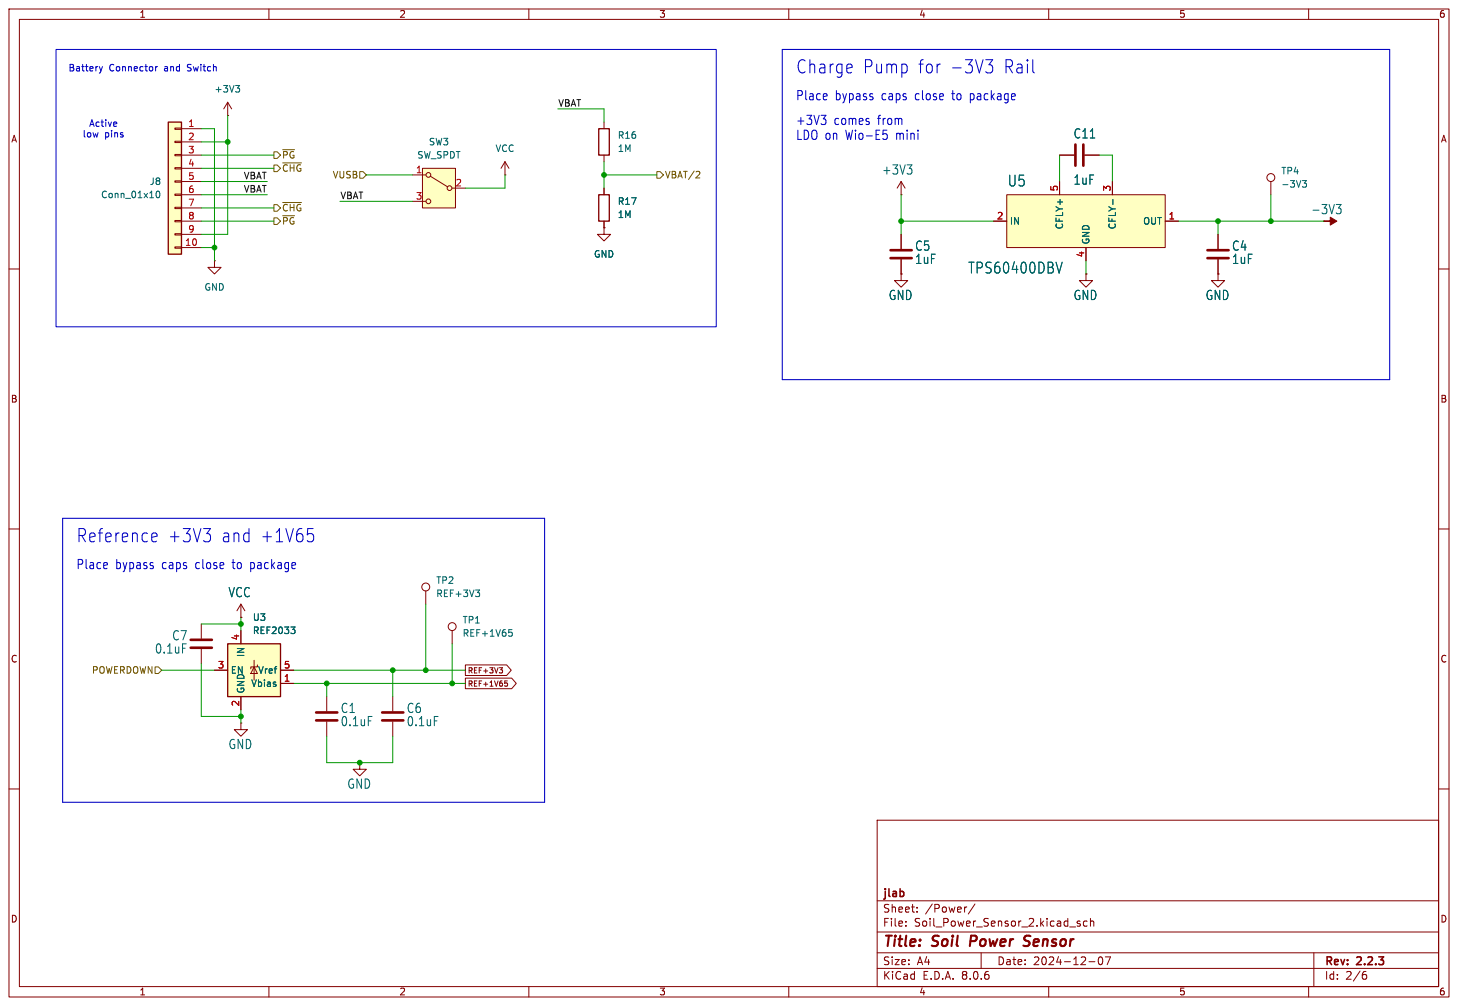
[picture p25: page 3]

LDO on Wio-E5 mini

jlab
Id: 2/6 Title: Soil Power Sensor File: Soil_Power_Sensor_2.kicad_sch Sheet: /Power/

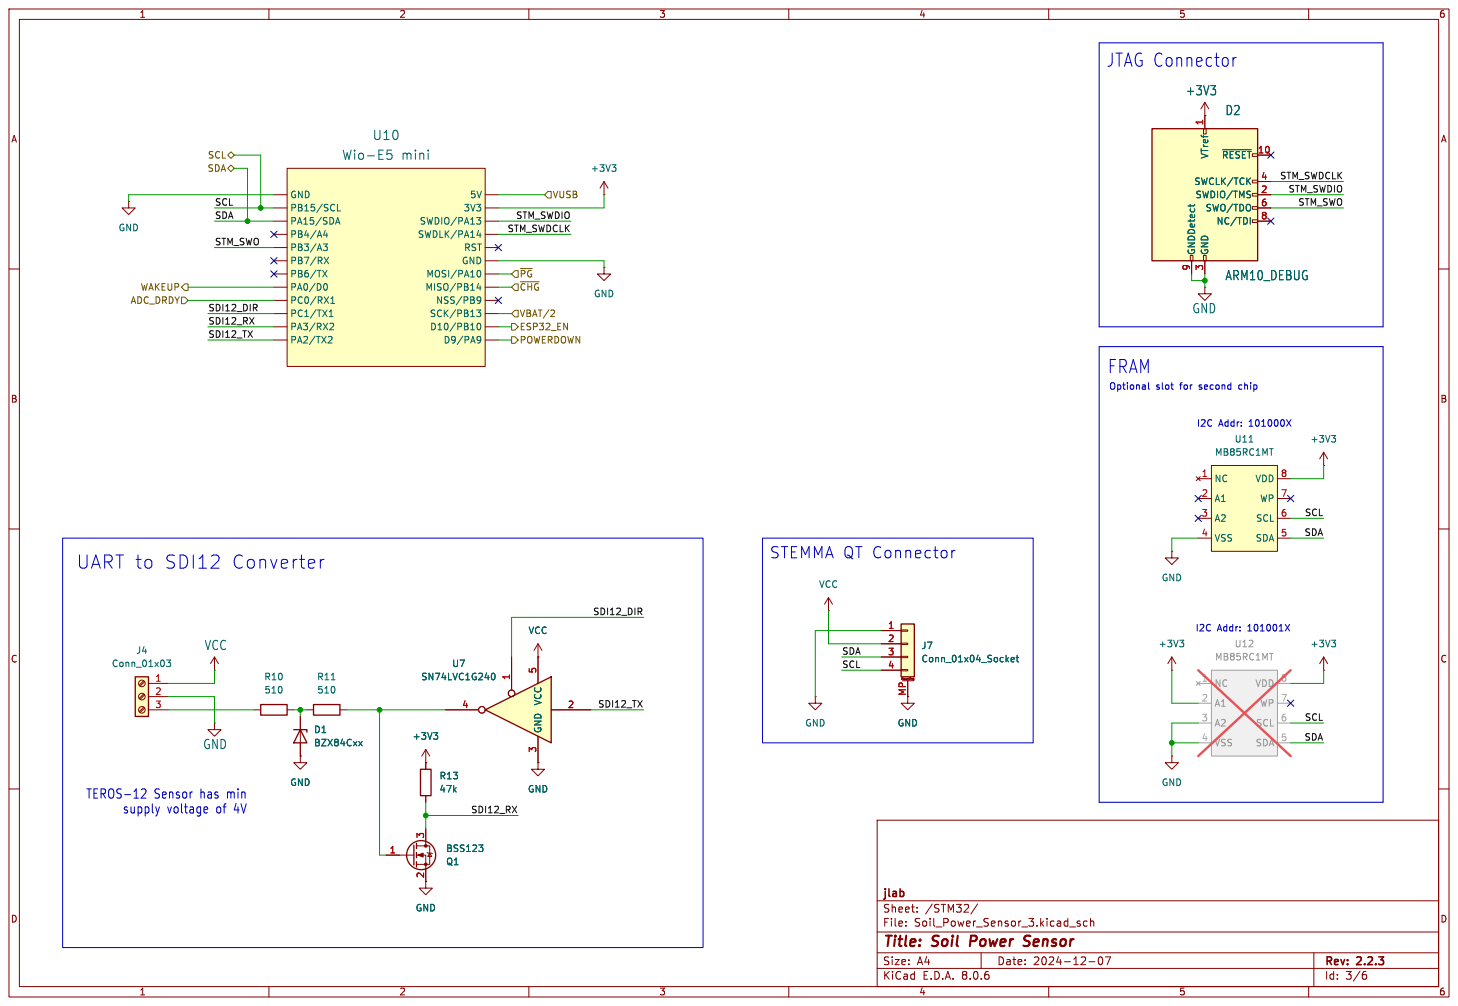
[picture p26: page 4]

3 SWCLK/TCK 4 SWO/TDO 6 NC/TDI 8 GNDDetect 9 +3V3

3 SWCLK/TCK 4 SWO/TDO 6 NC/TDI 8 GNDDetect 9 D2

I2C Addr: 101000X TEROS-12 Sensor has min

jlab
Id: 3/6 Title: Soil Power Sensor File: Soil_Power_Sensor_3.kicad_sch Sheet: /STM32/

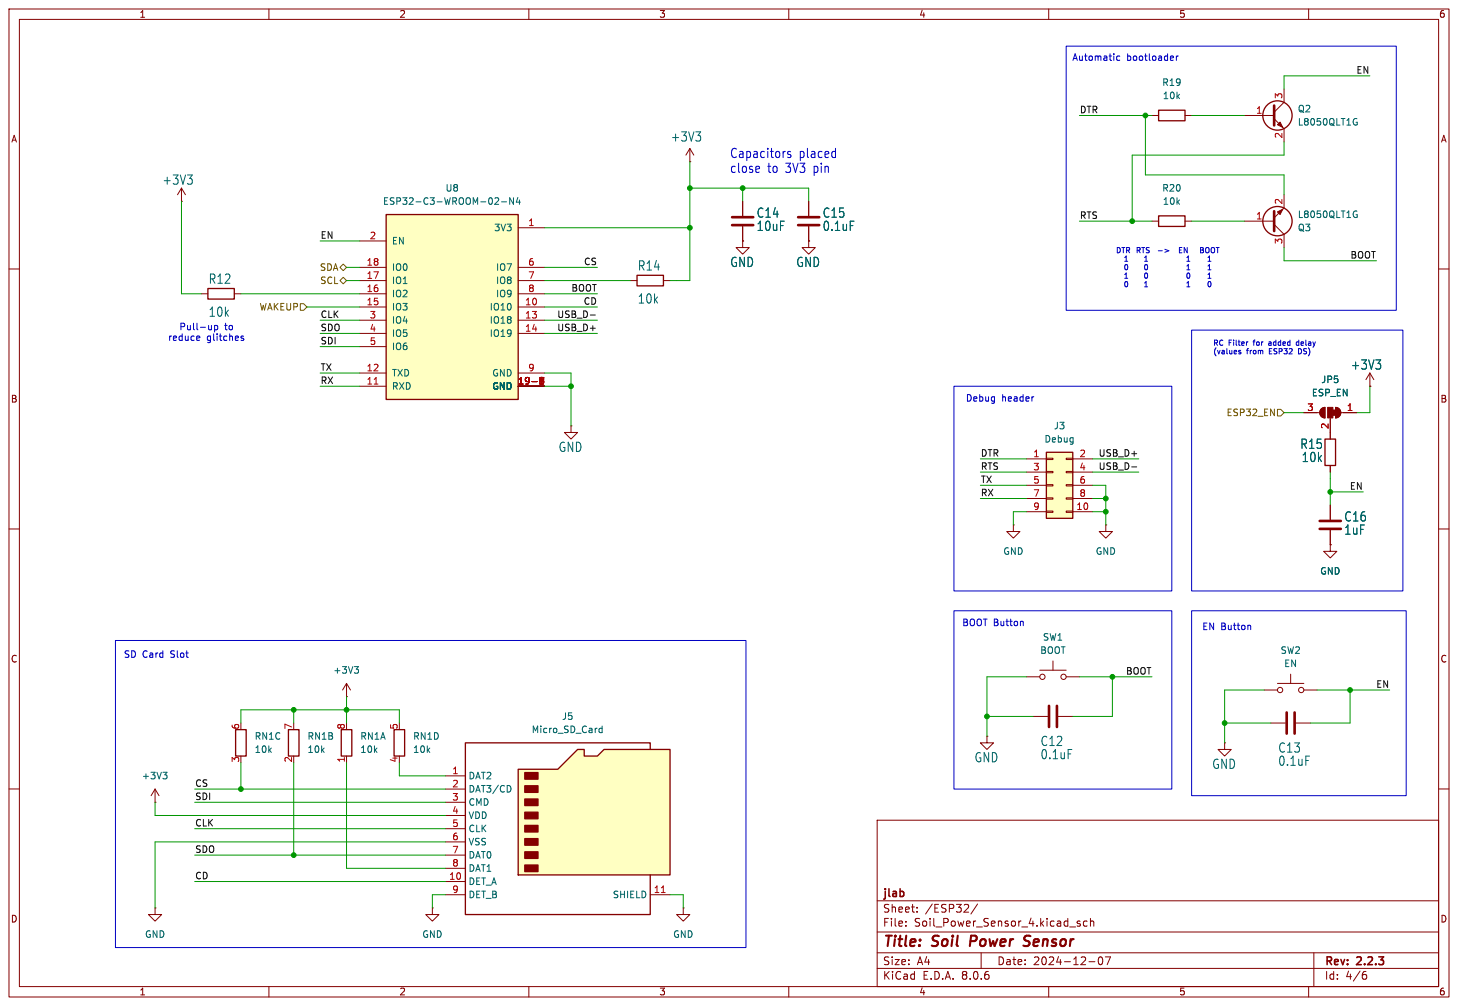
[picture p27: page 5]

RC Filter for added delay

jlab
Id: 4/6 Title: Soil Power Sensor File: Soil_Power_Sensor_4.kicad_sch Sheet: /ESP32/

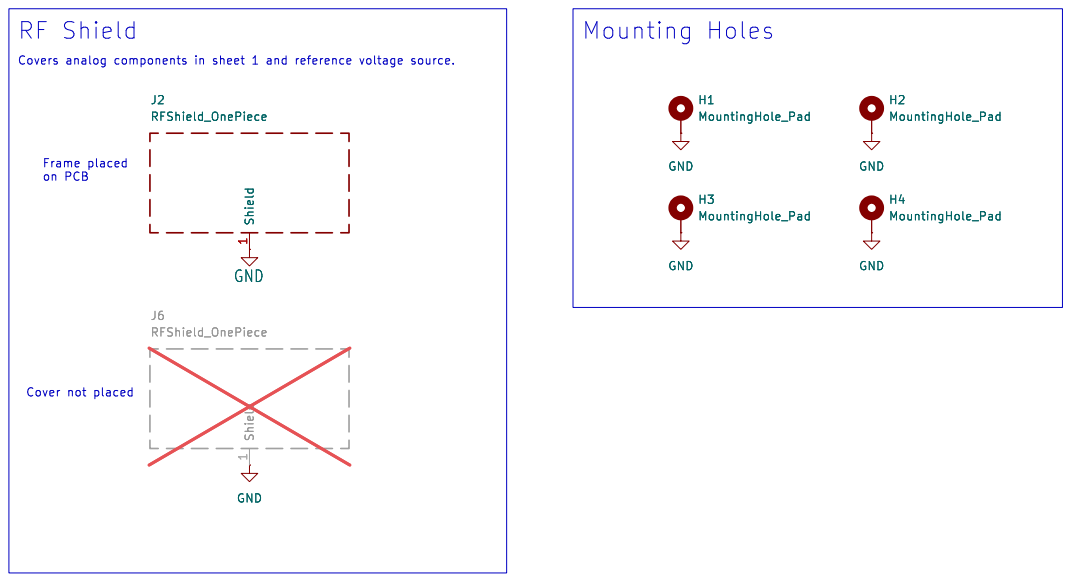
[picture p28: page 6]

on PCB RF Shield

jlab
Id: 5/6 Title: Soil Power Sensor File: hardware.kicad_sch Sheet: /Hardware/

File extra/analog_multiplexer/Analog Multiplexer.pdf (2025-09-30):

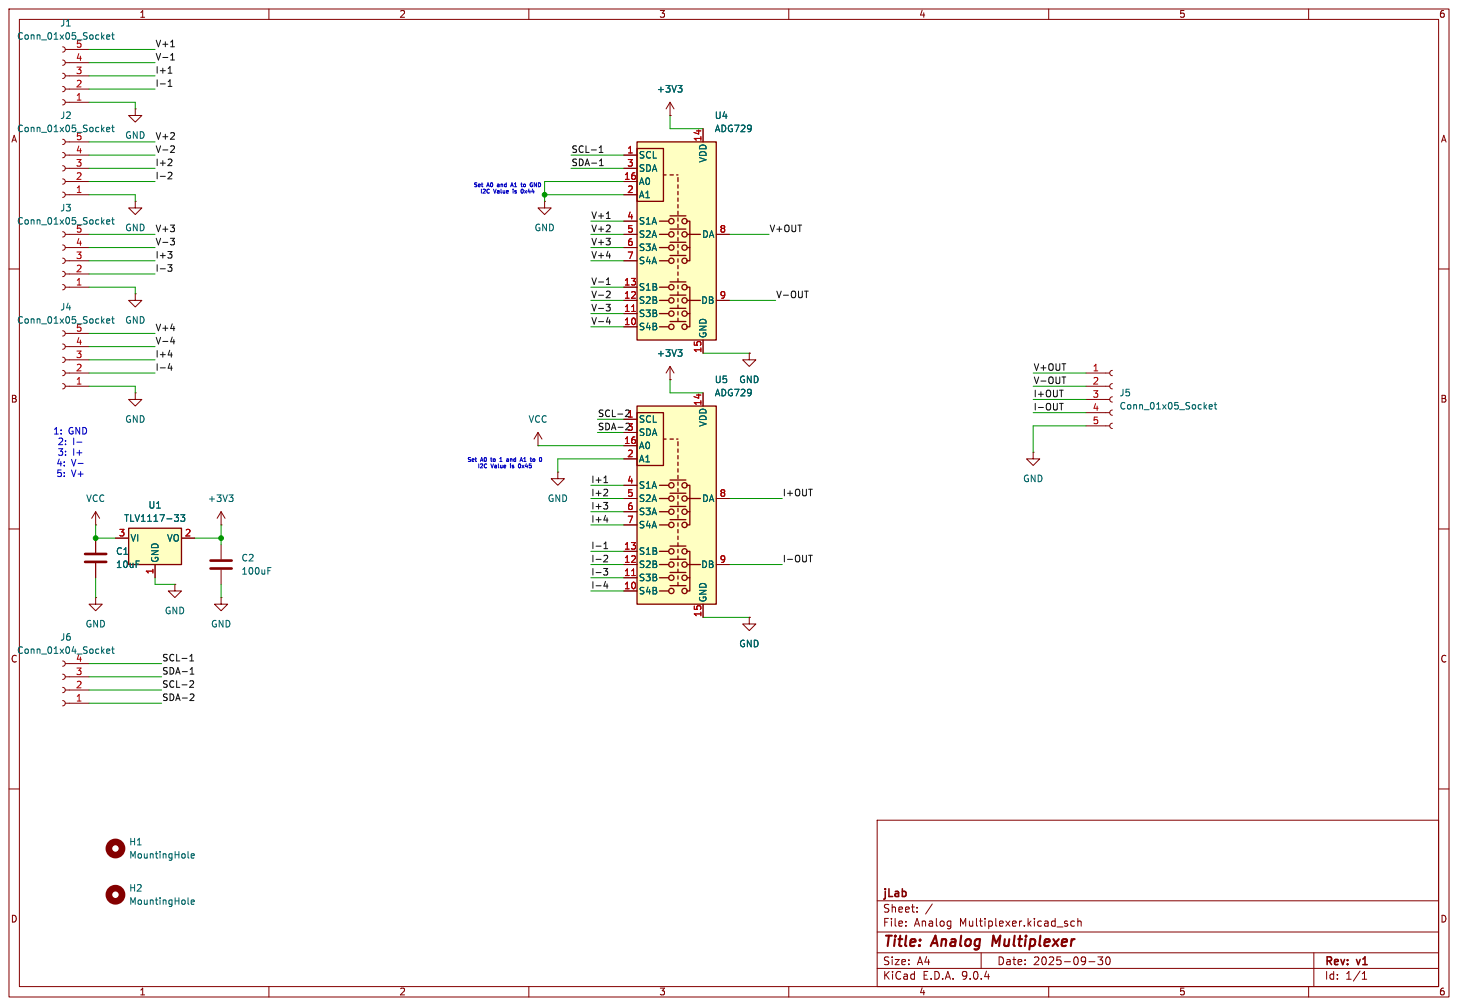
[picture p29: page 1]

Set A0 and A1 to GND

Set A0 to 1 and A1 to 0
I2C Value is 0x45

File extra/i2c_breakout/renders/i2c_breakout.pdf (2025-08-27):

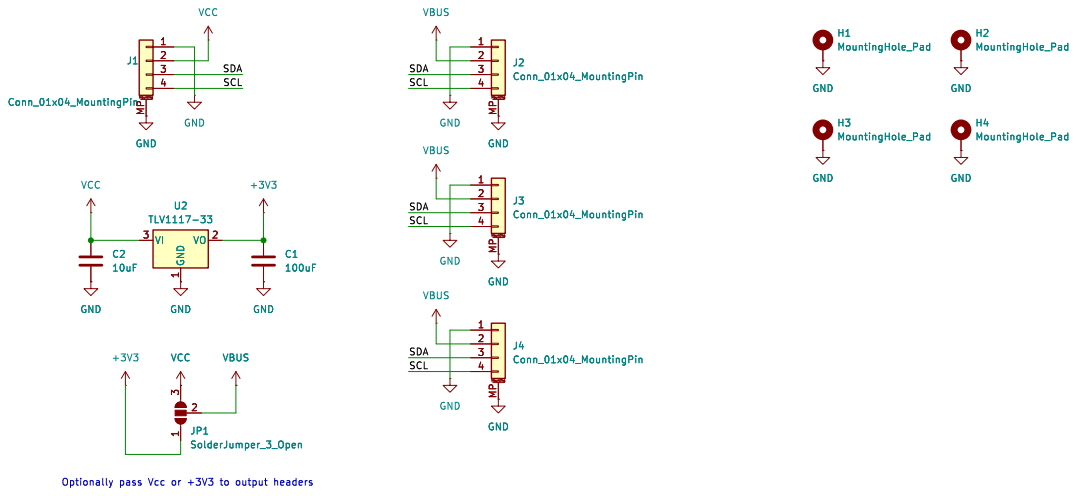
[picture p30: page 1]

SDA
SCL SCL SCL SDA

jlab
File: i2c_breakout.kicad_sch Sheet: /
Id: 1/1 Title: I2C Breakout Board

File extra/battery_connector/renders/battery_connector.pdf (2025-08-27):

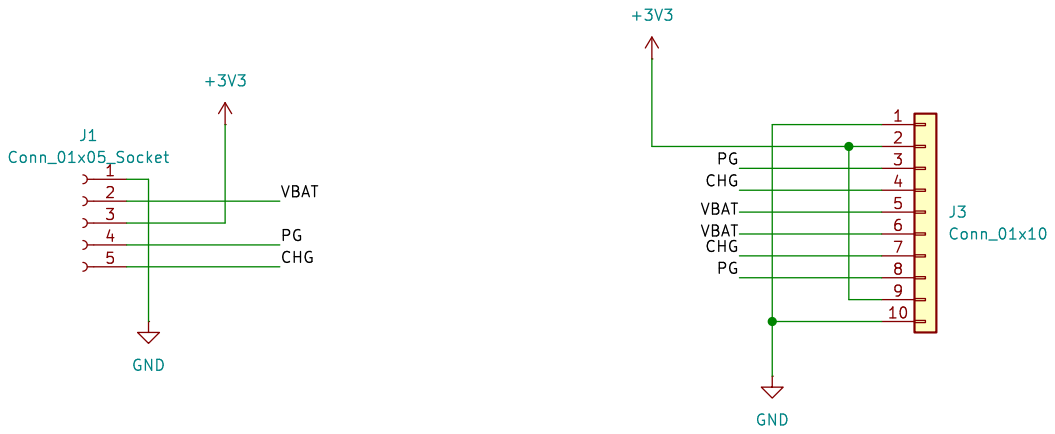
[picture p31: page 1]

Id: 1/1 Title: Battery Connector File: battery_connector.kicad_sch Sheet: /

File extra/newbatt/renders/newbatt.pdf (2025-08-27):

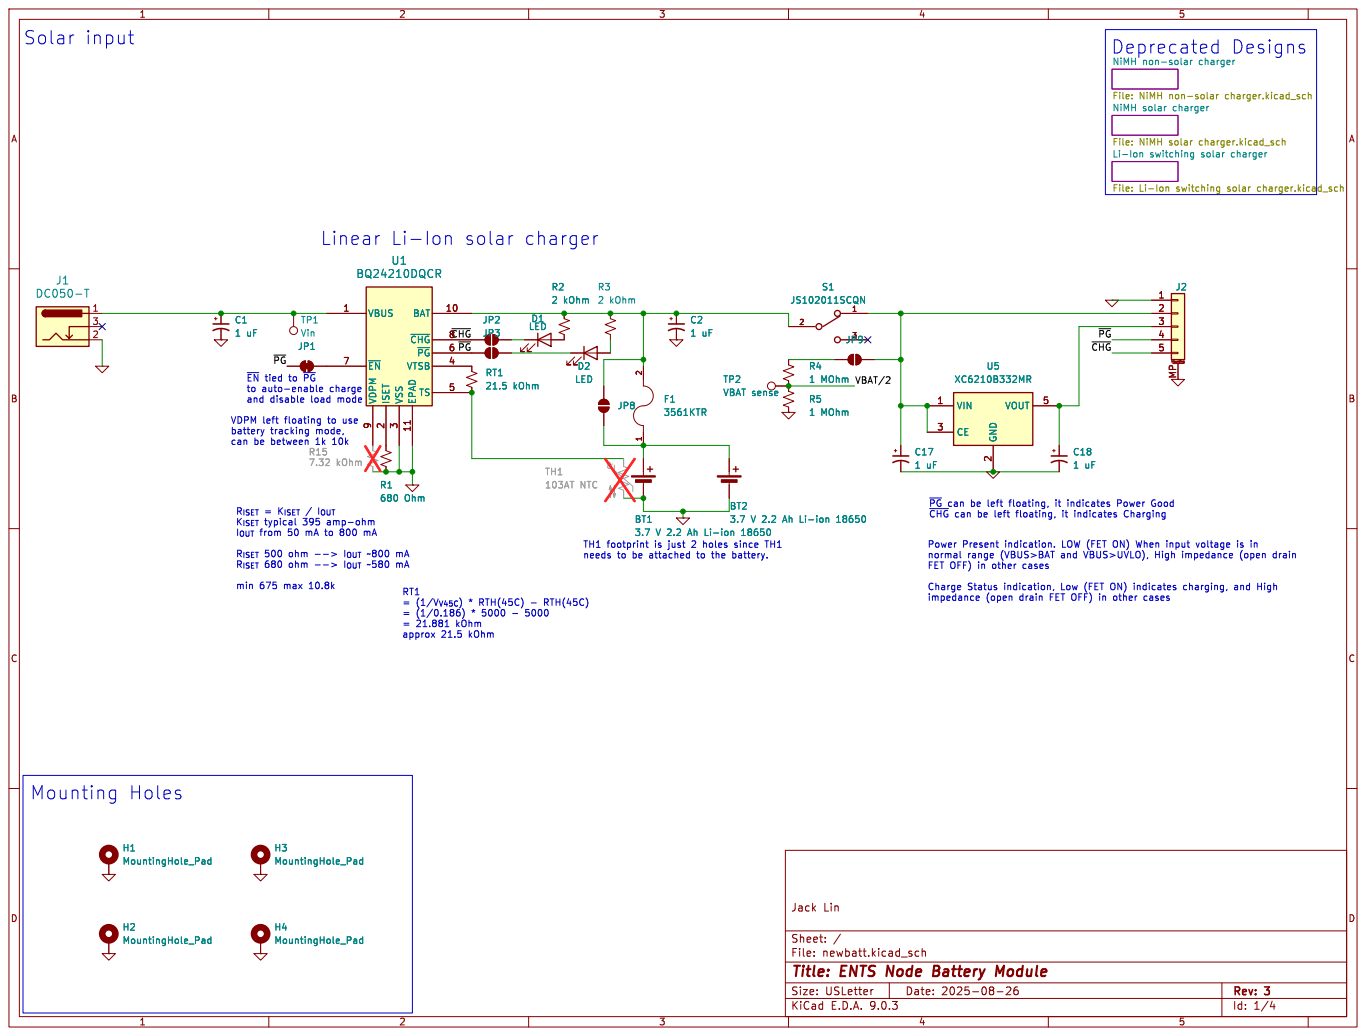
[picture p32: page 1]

3 EPAD 11 BAT 10 VTSB 4 TS 5 ~{EN} 7 ~{CHG} 8 ~{PG} 6 U1 BQ24210DQCR

3 EPAD 11 BAT 10 VTSB 4 TS 5 ~{EN} 7 ~{CHG} 8 ~{PG} 6 D2

~{EN}tied to ~{PG}

approx 21.5 kOhm Mounting Holes

Id: 1/4 Title: ENTS Node Battery Module

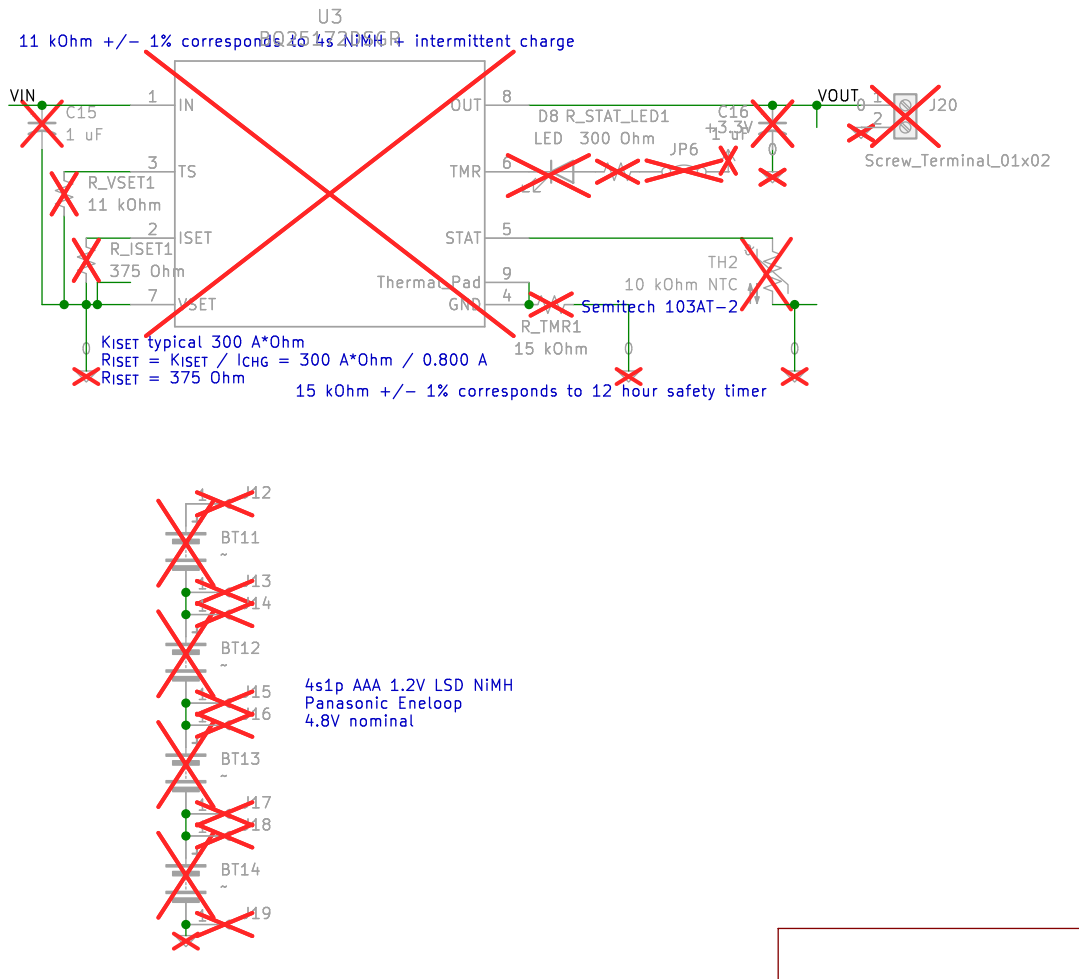
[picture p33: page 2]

R_{ISET} = K_{ISET} / I_{CHG} = 300 A*Ohm / 0.800 A R_{ISET} = 375 Ohm

Id: 3/4 Title: ENTS Node Battery Module

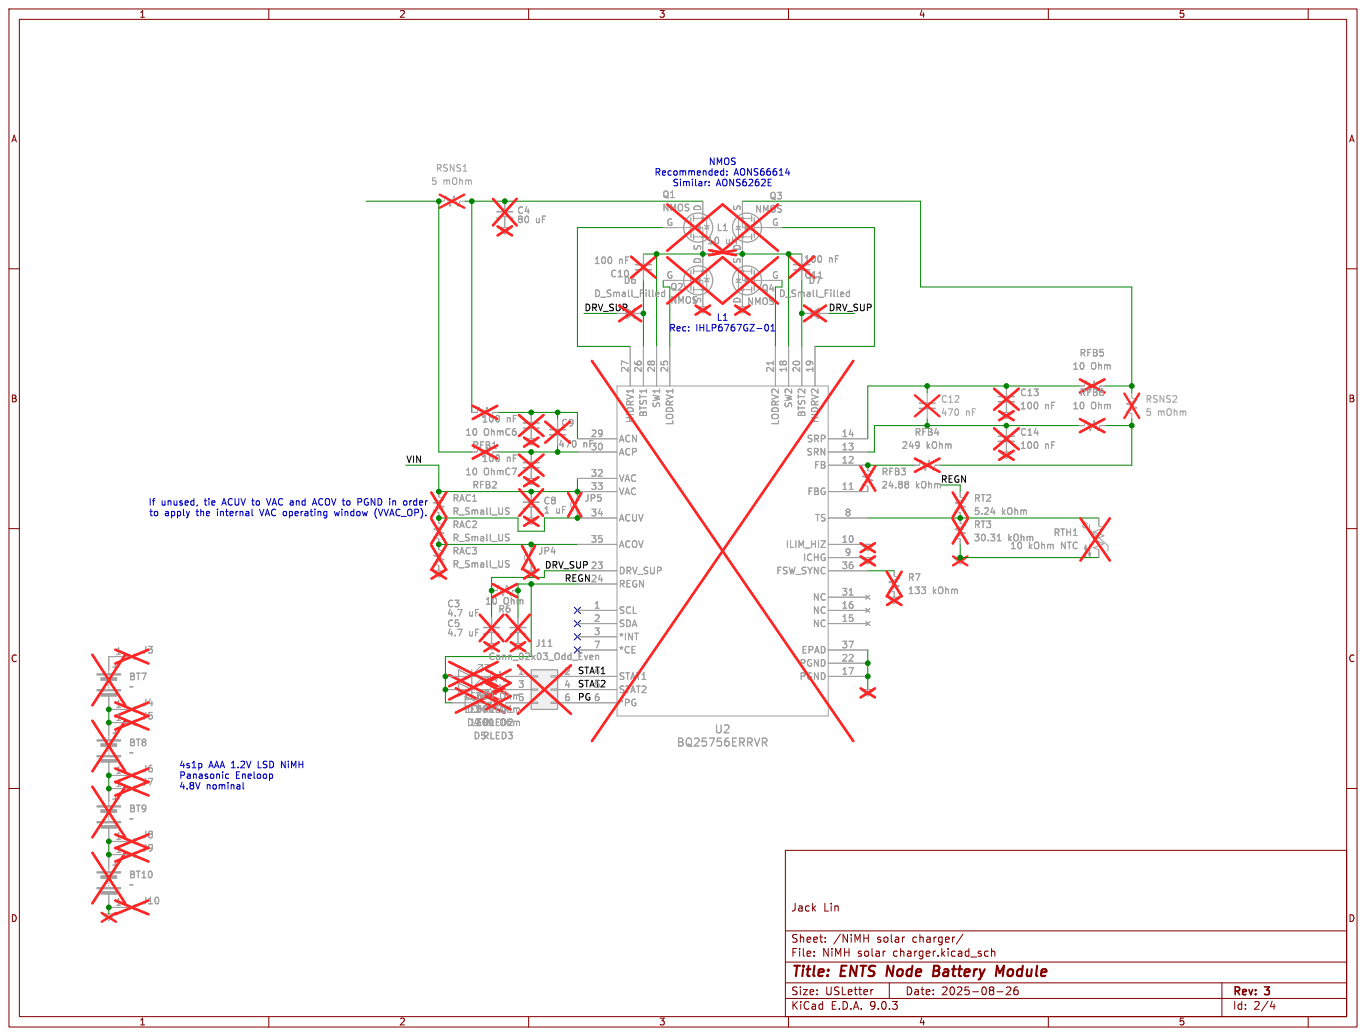
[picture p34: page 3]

If unused, tie ACUV to VAC and ACOV to PGND in order

Id: 2/4 Title: ENTS Node Battery Module


Id: 4/4 Title: ENTS Node Battery Module

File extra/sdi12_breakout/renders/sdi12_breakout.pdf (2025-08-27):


jLab
Id: 1/1 Title: ENTS SDI12 Breakout File: sdi12_breakout.kicad_sch Sheet: /

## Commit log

2024-03-07 Adding general improvements to sensor PCB
    [SDI-12.kicad_sch, Soil Power Sensor.csv, Soil Power Sensor.kicad_pcb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]
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2024-03-07 Moved hardware components to new sheet
    [SDI-12.kicad_sch, Soil Power Sensor.kicad_pcb, Soil Power Sensor.kicad_sch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]
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2024-03-08 Added solder point for Vcc
    [Soil_Power_Sensor_2.kicad_sch]
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2024-03-08 Added buttons for ESP32
    [Soil_Power_Sensor_4.kicad_sch]
2024-03-08 Fixed ERC errors
    [Soil Power Sensor.kicad_sch, Soil_Power_Sensor_1.kicad_sch, Soil_Power_Sensor_2.kicad_sch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]
2024-03-08 Updated SDI12 screw terminal
    [Soil_Power_Sensor_3.kicad_sch]
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2024-03-08 Updated annotations based on PCB position
    [Soil Power Sensor.kicad_pcb, Soil Power Sensor.kicad_sch, Soil_Power_Sensor_1.kicad_sch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]
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2024-04-12 Updated to kicad 8.0
    [Soil Power Sensor.kicad_sch, Soil_Power_Sensor_1.kicad_sch, Soil_Power_Sensor_2.kicad_sch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]
2024-05-31 Fixed BOM MPN values
    [Soil Power Sensor.csv, Soil Power Sensor.kicad_sch, Soil_Power_Sensor_1.kicad_sch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]
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2024-06-26 Removed old board files
    [Soil Power Sensorv1.kicad_pcb]
2024-06-26 Updated esp32 uart terminal
    [Soil Power Sensor.kicad_pcb, Soil_Power_Sensor_4.kicad_sch]
2024-07-22 Added STEMMA QT connector
    [Soil Power Sensor.kicad_pcb, Soil_Power_Sensor_3.kicad_sch]
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2024-07-24 Placed microSD card slot
    [Soil Power Sensor.kicad_pcb]
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2024-07-24 Moved everything within board outline
    [Soil Power Sensor.kicad_pcb]
2024-07-25 Added resistor network for SD card
    [Soil Power Sensor.kicad_pcb, Soil_Power_Sensor_1.kicad_sch, Soil_Power_Sensor_4.kicad_sch]
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2024-07-26 Fixed revision number on board
    [Soil Power Sensor-B_Cu.gbl, Soil Power Sensor-B_Mask.gbs, Soil Power Sensor-B_Paste.gbp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]
2024-07-30 Updated BOM for JLCPCB
    [Soil Power Sensor.csv, Soil_Power_Sensor_1.kicad_sch, Soil_Power_Sensor_2.kicad_sch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]
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2024-07-31 Updated BOM with necessary JCLPCB part numbers
    [Soil Power Sensor.csv, Soil_Power_Sensor_1.kicad_sch, Soil_Power_Sensor_3.kicad_sch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]
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2024-08-14 Version bump to 2.2.2
    [Soil Power Sensor.kicad_pcb, Soil Power Sensor.kicad_sch, Soil_Power_Sensor_1.kicad_sch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]
2024-08-14 Updated LCSC parts numbers
    [Soil_Power_Sensor_3.kicad_sch, Soil_Power_Sensor_4.kicad_sch]
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2024-08-20 Regenerated files with kicad-cli script
    [Soil Power Sensor-B_Cu.gbl, Soil Power Sensor-B_Mask.gbs, Soil Power Sensor-B_Paste.gbp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]
2024-09-04 Added DevEUI to silkscreen
    Closes #52
    [Soil Power Sensor.kicad_pcb]
2024-09-04 Moved silkscreen for analog terminals
    Closes #51
    [Soil Power Sensor.kicad_pcb]
2024-09-04 Fixed microSD card
    Closes #54
    [1040310811.stp, Soil Power Sensor.kicad_pcb, Soil_Power_Sensor_4.kicad_sch]
2024-09-04 Added wakeup line for esp32
    Closes #48
    [Soil Power Sensor.kicad_pcb, Soil Power Sensor.kicad_sch, Soil_Power_Sensor_3.kicad_sch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]
2024-09-05 Fixed misc issues during ordering
    [Soil Power Sensor-B_Cu.gbl, Soil Power Sensor-B_Mask.gbs, Soil Power Sensor-B_Paste.gbp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]
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2024-10-09 Battery module based on the BQ25172 NiMH BMS. This commit contains DRC errors and should NOT be fabbed
    [BQ25172_DSG0008A.stp, newbatt.kicad_pcb, newbatt.kicad_sch]
2024-10-21 BQ25756E NiMH solar charging
    [newbatt.kicad_pcb, newbatt.kicad_sch]
2024-10-24 18650 Li-Ion 2 parallel design using BQ24210
    [Li-Ion switching solar charger.kicad_sch, NiMH non-solar charger.kicad_sch, NiMH solar charger.kicad_sch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]
2024-11-07 battery switch, fuse, and rerouted traces
    [Li-Ion switching solar charger.kicad_sch, NiMH non-solar charger.kicad_sch, NiMH solar charger.kicad_sch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]
2024-11-09 glass fuse and updated footprints
    [newbatt-B_Cu.gbr, newbatt-B_Mask.gbr, newbatt-B_Paste.gbr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]
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2024-11-13 Updated BoM with LCSC, Digikey. Updated 18650 battery clip footprint with 67.2mm spacing for 65mm and 67mm cells
    [Li-Ion switching solar charger.kicad_sch, NiMH non-solar charger.kicad_sch, NiMH solar charger.kicad_sch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]
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2024-11-15 Added battery module header
    [Soil_Power_Sensor_2.kicad_sch]
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2024-11-16 Reviewed with John, updated VDPM and resistor values and barrel jack
    [newbatt-B_Cu.gbr, newbatt-B_Mask.gbr, newbatt-B_Paste.gbr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]
2024-11-16 Fixed issues from design review
    [Soil Power Sensor.kicad_pcb, Soil Power Sensor.kicad_sch, Soil_Power_Sensor_1.kicad_sch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]
2024-12-06 Added 3.3V linear regulator
    [ENTS Node Battery Module.csv, newbatt.kicad_pcb, newbatt.kicad_sch]
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2024-12-08 Fixed issue with battery connector
    [Soil Power Sensor.kicad_pcb, Soil Power Sensor.kicad_sch, Soil_Power_Sensor_2.kicad_sch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]
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2024-12-08 Fixed silkscreen for panelization
    [Soil Power Sensor-B_Cu.gbl, Soil Power Sensor-B_Mask.gbs, Soil Power Sensor-B_Paste.gbp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]
2024-12-08 Fixed drill files
    [Soil Power Sensor-B_Cu.gbl, Soil Power Sensor-B_Mask.gbs, Soil Power Sensor-B_Paste.gbp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]
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2025-08-15 Added battery connector files
    [battery_connector.kicad_pcb, battery_connector.kicad_sch]
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2025-08-21 Added adapter and debugger files
    [usb_to_ttl.kicad_pcb, usb_to_ttl.kicad_sch]
2025-08-22 Updated adapter/debugger schematic and PCB files
    [usb_to_ttl.kicad_pcb, usb_to_ttl.kicad_sch]
2025-08-25 1x10 pin header --> 5 pin JST
    [Li-Ion switching solar charger.kicad_sch, NiMH non-solar charger.kicad_sch, NiMH solar charger.kicad_sch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]
2025-08-25 JST PH --> JST SH
    [SM05B-SRSS-TB.STEP, newbatt.kicad_pcb, newbatt.kicad_sch]
2025-08-26 Added design files from tutorial]
    [i2c_breakout.kicad_pcb, i2c_breakout.kicad_sch]
2025-08-26 Added jumper for power passthrough
    [i2c_breakout.kicad_pcb, i2c_breakout.kicad_sch]
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2025-08-26 Added LCSC part numbers
    [i2c_breakout-B_Cu.gbl, i2c_breakout-B_Mask.gbs, i2c_breakout-B_Paste.gbp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]
2025-08-27 Moved newbatt to extra
    [BQ25172_DSG0008A.stp, ENTS Node Battery Module.csv, Li-Ion switching solar charger.kicad_sch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]
2025-08-27 Removed old production files
    [newbatt-B_Cu.gbl, newbatt-B_Cu.gbr, newbatt-B_Mask.gbr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]
2025-08-27 Generated production for newbatt
    [Li-Ion switching solar charger.kicad_sch, NiMH non-solar charger.kicad_sch, NiMH solar charger.kicad_sch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]
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2025-08-27 Renamed 'SDI12 Connector' to sdi12_breakout
    [sdi12_breakout.kicad_pcb, sdi12_breakout.kicad_sch]
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2025-09-23 Analog Multiplexer
    Analog Multiplexer Schematic and Design, needs final touch ups which should be done today or tmr
    [Analog Multiplexer.kicad_pcb, Analog Multiplexer.kicad_sch]
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2025-09-30 Fixed connection to SUSPEND pins
    [usb_to_ttl.kicad_pcb, usb_to_ttl.kicad_sch]
2025-09-30 Fixed TX/RX connection on the board
    [usb_to_ttl.kicad_pcb]
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
